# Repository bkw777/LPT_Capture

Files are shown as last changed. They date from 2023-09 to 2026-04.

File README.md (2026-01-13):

**NOTE: Only the top/default DB25_MicroUSB_BASIC version is tested and known good.**  
**All other versions are untested guesswork.**

# LPT Capture
Capture the output from a parallel printer port.

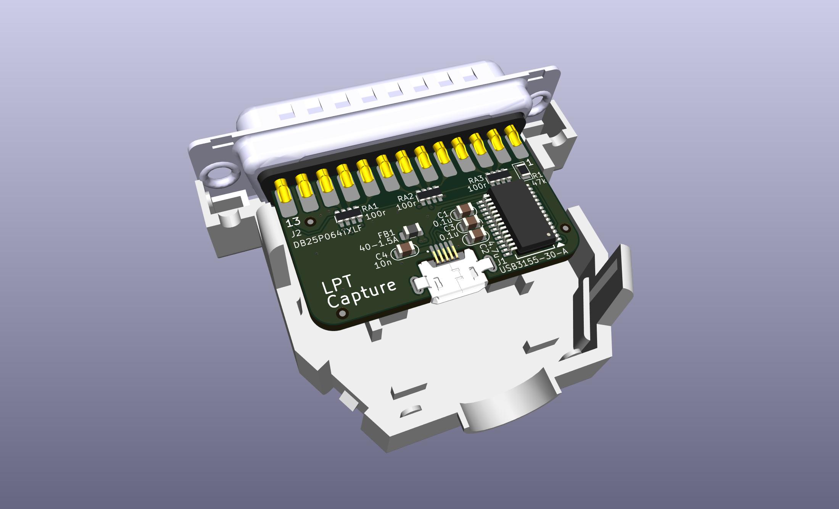
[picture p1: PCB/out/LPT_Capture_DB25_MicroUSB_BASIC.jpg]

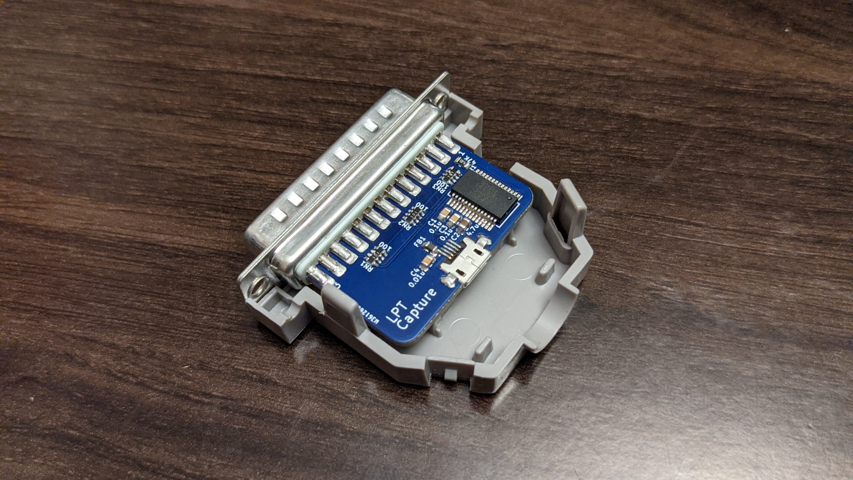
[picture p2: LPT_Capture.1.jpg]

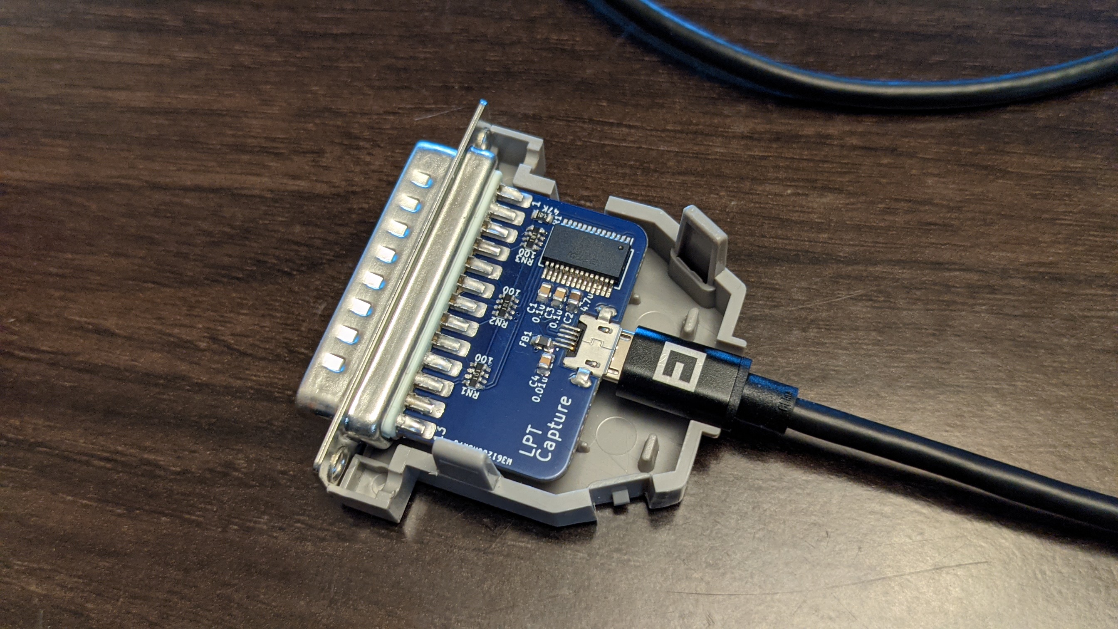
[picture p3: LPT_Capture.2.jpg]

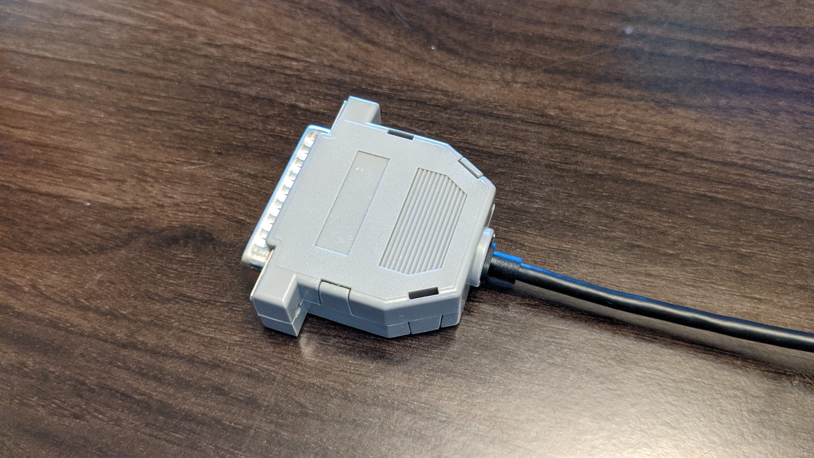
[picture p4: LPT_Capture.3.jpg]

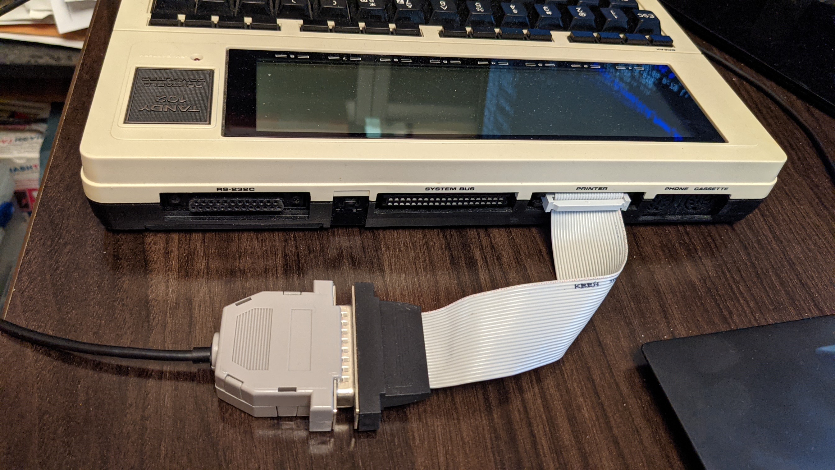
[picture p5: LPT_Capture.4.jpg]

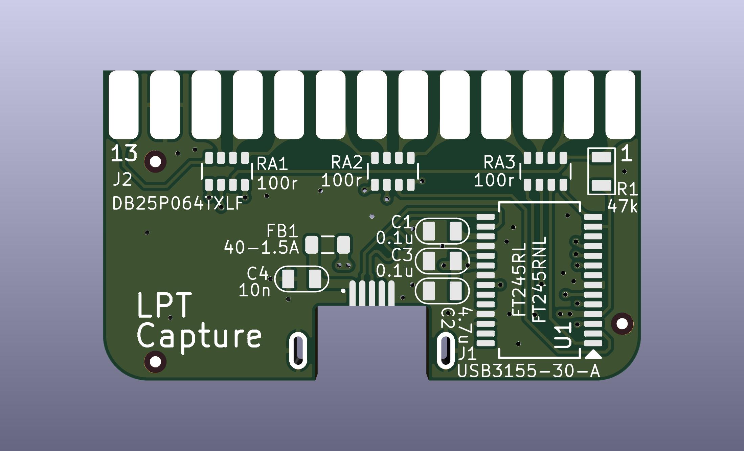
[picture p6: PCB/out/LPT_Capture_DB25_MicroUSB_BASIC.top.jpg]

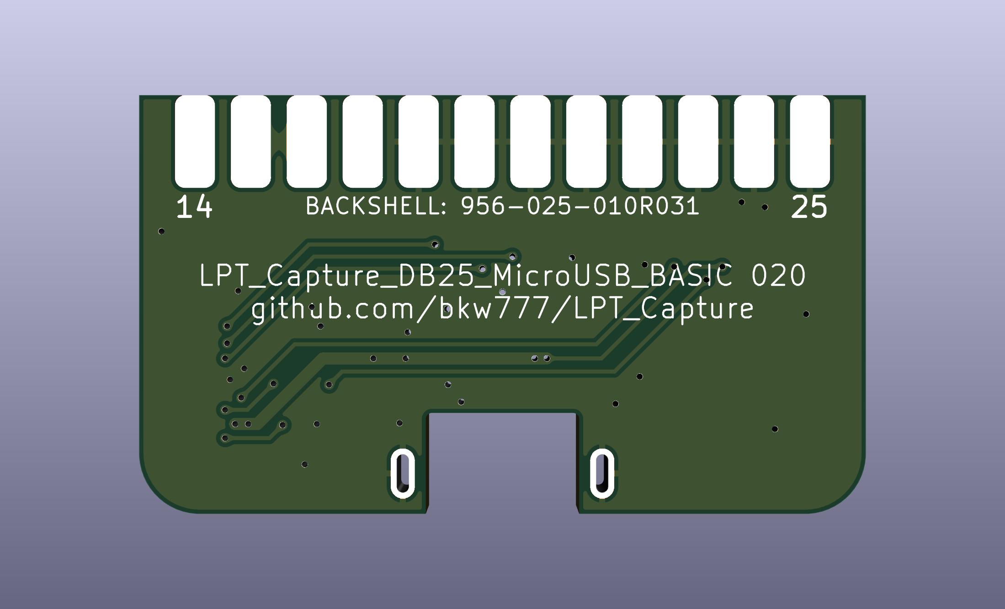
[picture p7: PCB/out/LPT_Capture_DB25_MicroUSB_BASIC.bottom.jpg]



PCB: [PCBWAY](https://www.pcbway.com/project/shareproject/LPT_Capture.html)  
BOM: [DigiKey](https://www.digikey.com/short/j7w00c9c)

# Usage
Plug the device directly into the parallel printer port on a vintage computer.  
Connect a modern machine to the mico-usb port.

The device appears as a usb-serial adapter to the modern machine. Drivers are standard in any modern os or platform.  
Use any serial comm program like PuTTY or TeraTerm or minicom or gnu screen etc to read the COM port.  
It doesn't matter what baud rate you select in the comm program.

Print to the LPT port on the vintage machine.

Read the data from the COM port on the modern machine.

This device essentially takes the place of a printer, and only only impliments the basic original Centronics interface, no ieee1284 epp ecp bi-directional etc.

# Other Versions
The default "DB25 MicroUSB BASIC" version above is tested.  
None of the rest of these are tested yet.

[DB25 MicroUSB FANCY](README_DB25_MicroUSB_FANCY.md)  
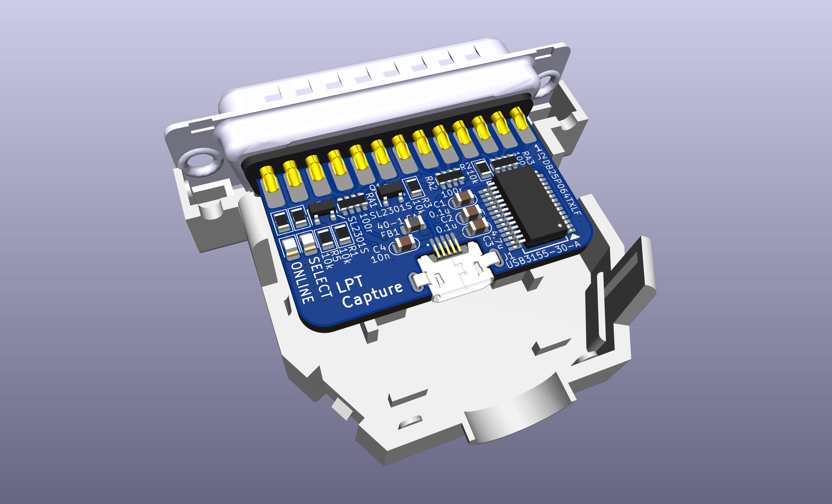
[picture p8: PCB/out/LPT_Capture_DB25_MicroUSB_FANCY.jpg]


[DB25 USBC BASIC](README_DB25_USBC_BASIC.md)  
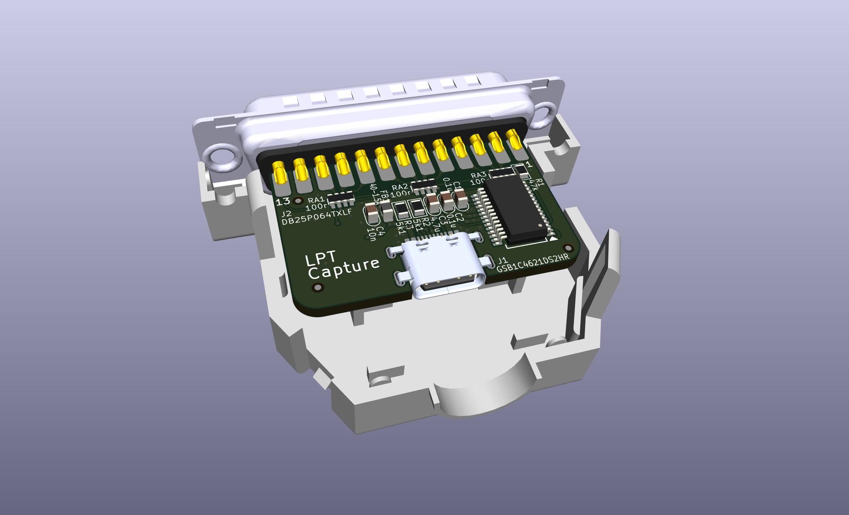
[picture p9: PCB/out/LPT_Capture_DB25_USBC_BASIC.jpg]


[DB25 USBC FANCY](README_DB25_USBC_FANCY.md)  
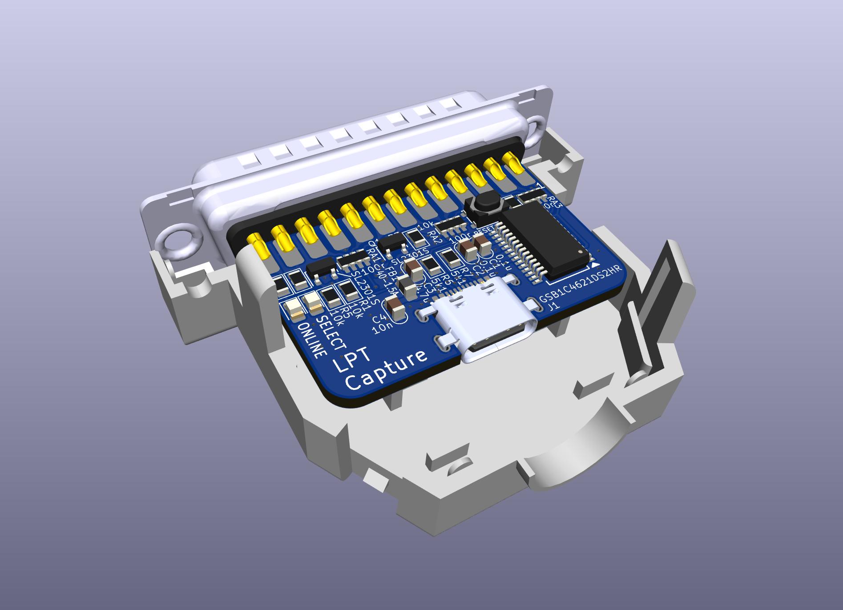
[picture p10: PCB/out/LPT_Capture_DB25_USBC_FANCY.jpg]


[CN36 USBC FANCY](README_CN36_USBC_FANCY.md)
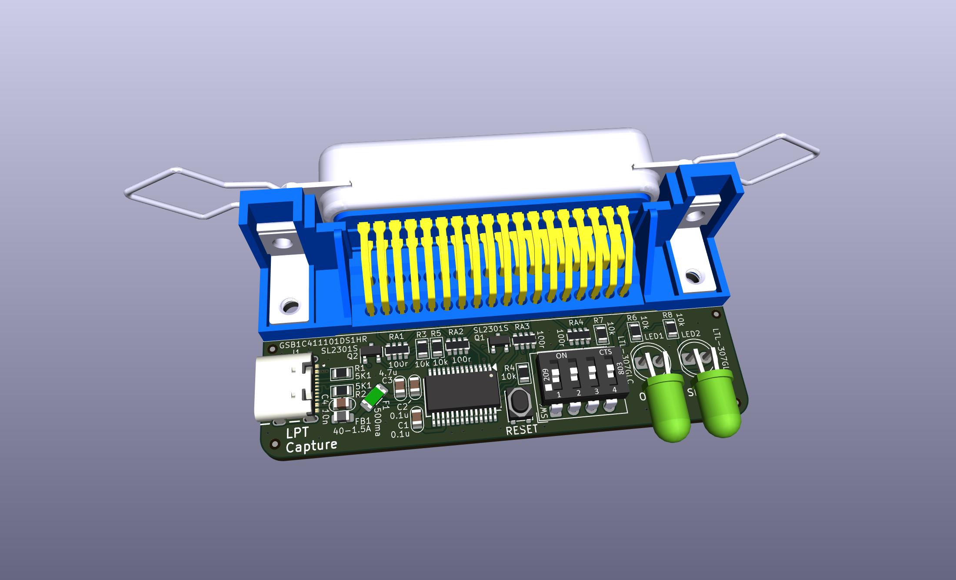
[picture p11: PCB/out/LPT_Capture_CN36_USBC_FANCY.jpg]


# Credits
[LptCap](https://www-user.tu-chemnitz.de/~heha/basteln/PC/LptCap/index.en.htm)

Differences:  
* KiCad instead of Eagle
* SSOP chip instead of QFN - easier to hand solder
* 0805 passives instead of 0603 - easier to hand solder
* microusb or usbc instead of miniusb
* mid-mount usb port - positions the plug in the center of the cable opening
* Snap-together backshell instead of screws & nuts
* VCCIO powered by VCC (5V) instead of 3V3OUT - LPT signals are 5V
* VBUS & VCC power conditioning per FT245R datasheet
* "fancy" versions impliment more signals (ONLINE, /SELIN, /RESET, /ERROR)
* CN36 version adds Peripheral Logic High and 5V power

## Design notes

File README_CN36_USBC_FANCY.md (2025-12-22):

# LPT Capture
Capture the output from a parallel printer port.

WIP NOT TESTED

* Centronics 36F  
* USB-C  
* ONLINE, /SELIN, /RESET signals  
* LEDS for ONLINE & /SELIN

This version is useful for hosts that don't have a standard IBM style db25 parallel printer port, but do have a printer cable that ends in a standard 36 pin Centronics plug.  
Examples: TRS-80 Model I, Model 100


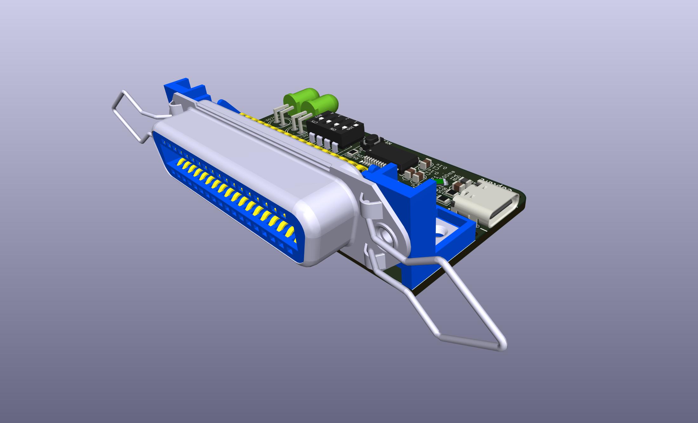
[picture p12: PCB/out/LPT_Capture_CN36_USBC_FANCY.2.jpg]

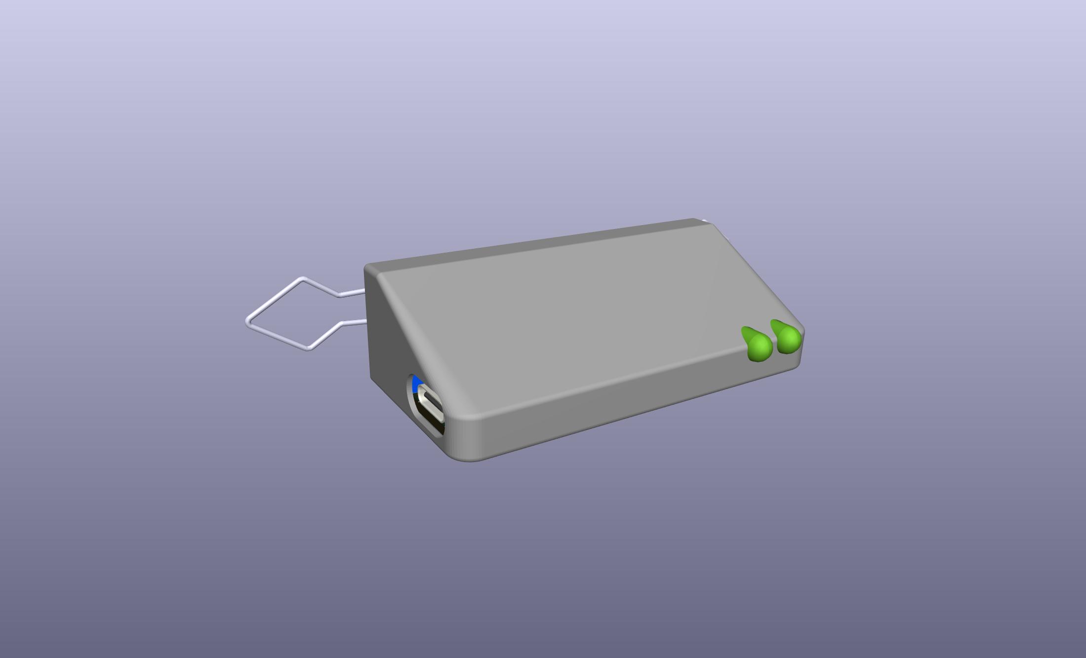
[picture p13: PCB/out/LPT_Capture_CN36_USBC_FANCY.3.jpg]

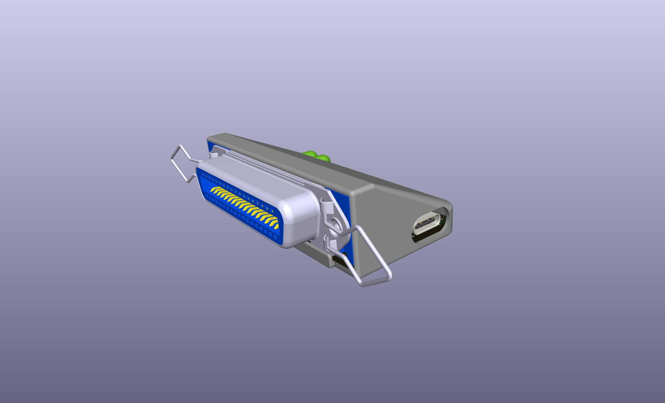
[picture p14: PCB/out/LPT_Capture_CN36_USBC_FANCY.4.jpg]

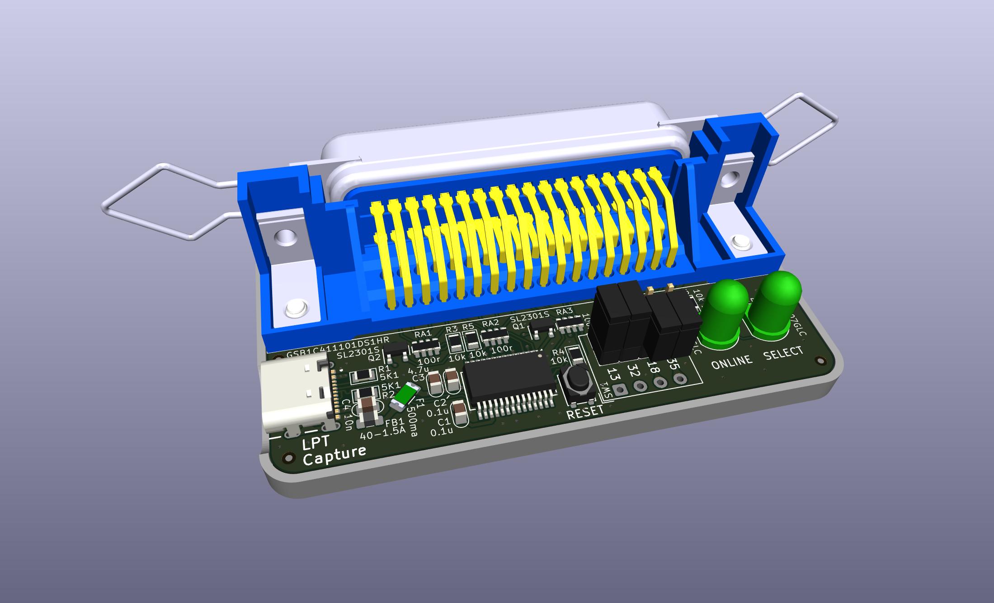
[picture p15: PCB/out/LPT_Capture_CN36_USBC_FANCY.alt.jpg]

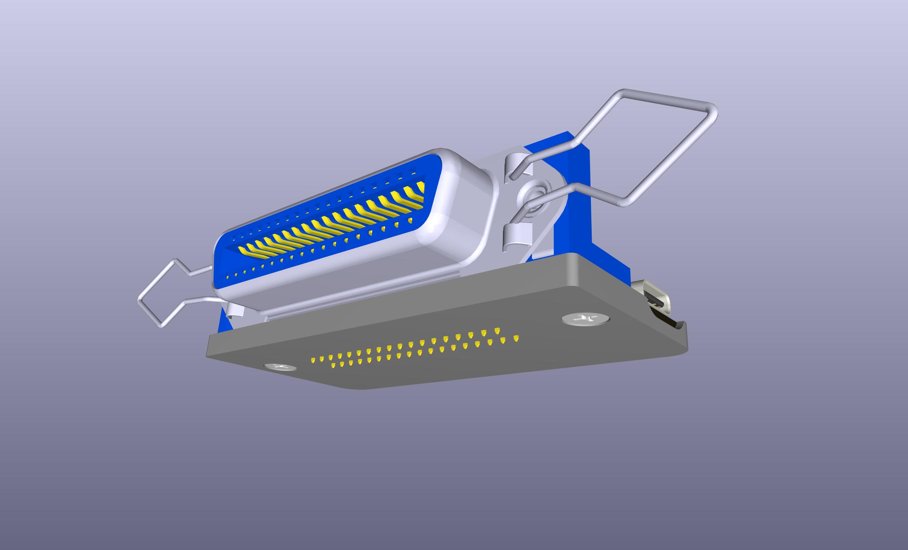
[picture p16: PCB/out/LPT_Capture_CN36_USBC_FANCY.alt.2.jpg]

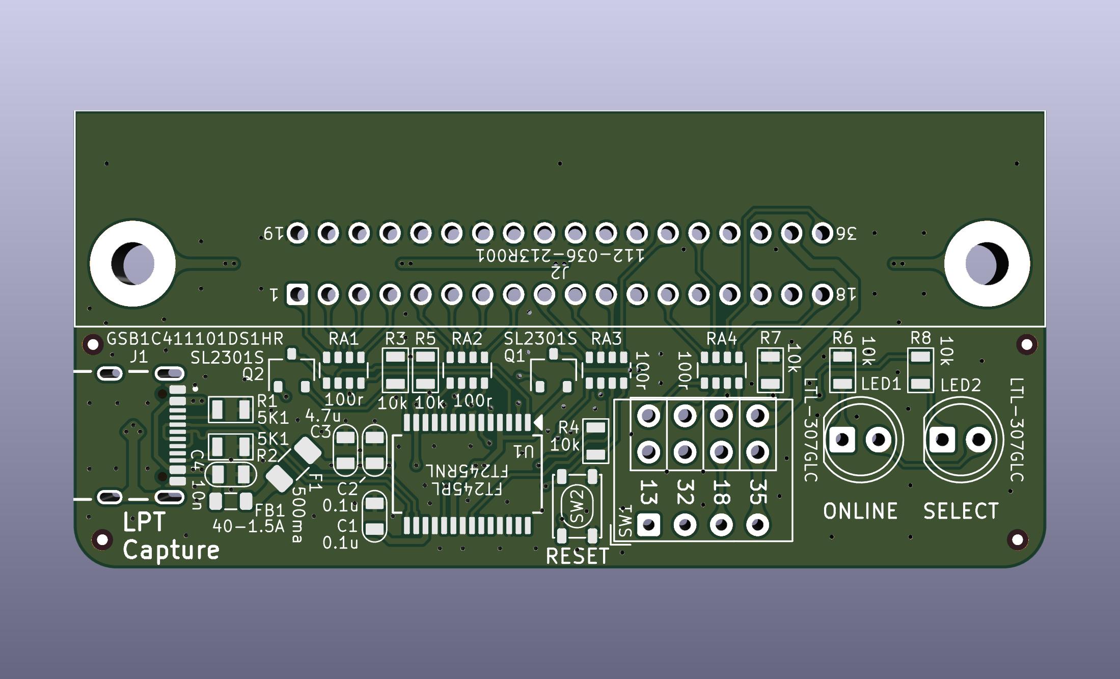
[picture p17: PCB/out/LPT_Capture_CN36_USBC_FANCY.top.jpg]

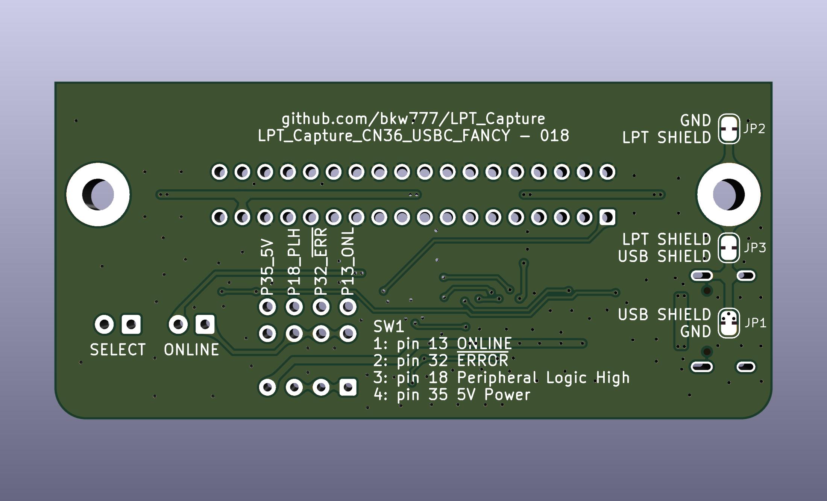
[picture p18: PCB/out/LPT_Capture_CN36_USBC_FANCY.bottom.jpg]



<!-- PCB: [PCBWAY](https://www.pcbway.com/project/shareproject/LPT_Capture.html)  --> 
BOM: [bom.csv](PCB/out/LPT_Capture_CN36_USBC_FANCY.bom.csv) <!-- [DigiKey](https://www.digikey.com/short/j7w00c9c) -->

# Credits
[LptCap](https://www-user.tu-chemnitz.de/~heha/basteln/PC/LptCap/index.en.htm)

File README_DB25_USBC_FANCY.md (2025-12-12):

# LPT Capture

WIP NOT TESTED

* DB25
* USB-C  
* ONLINE, /RESET, /SELIN  
* LEDS on ONLINE, /SELIN


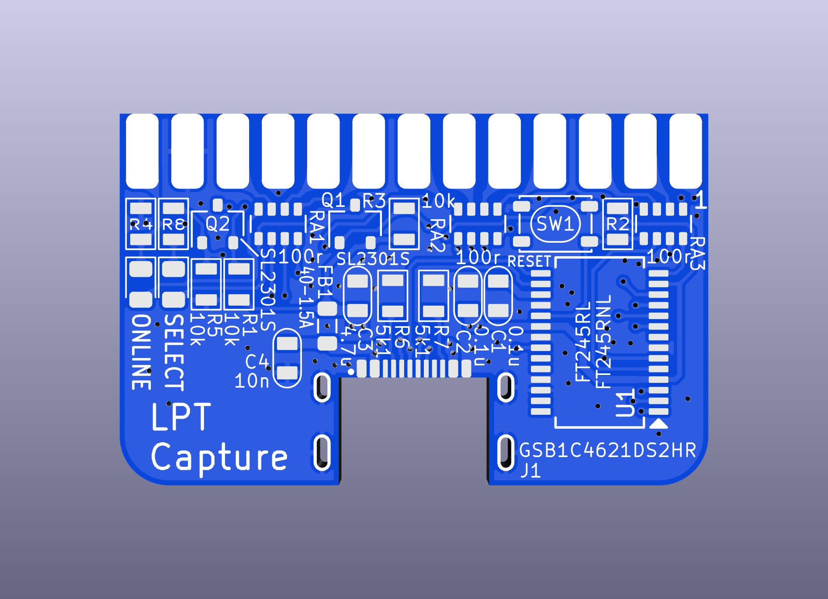
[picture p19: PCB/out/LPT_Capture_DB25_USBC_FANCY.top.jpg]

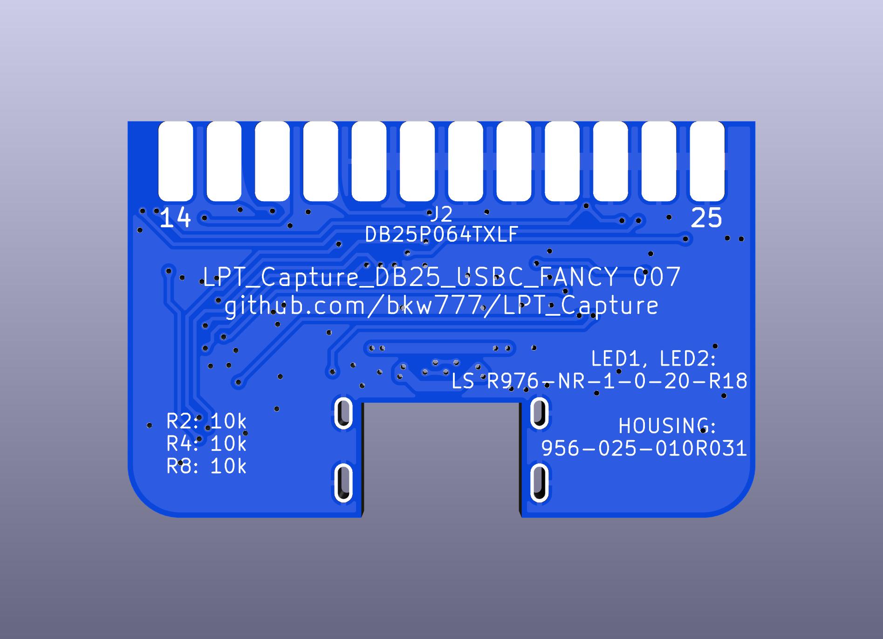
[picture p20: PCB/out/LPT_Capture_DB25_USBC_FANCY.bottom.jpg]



<!-- PCB: [OSHPark](https://oshpark.com/shared_projects/DqbtiuyI), [PCBWAY](https://www.pcbway.com/project/shareproject/LPT_Capture.html)  -->
BOM: [bom.csv](PCB/out/LPT_Capture_DB25_USBC_FANCY.bom.csv)  <!-- [DigiKey](https://www.digikey.com/short/hpfd7prz) -->

# Credits
[LptCap](https://www-user.tu-chemnitz.de/~heha/basteln/PC/LptCap/index.en.htm)

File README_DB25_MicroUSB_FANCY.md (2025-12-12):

# LPT Capture

WIP NOT TESTED

* DB25  
* MicroUSB  
* ONLINE, /RESET, /SELIN  
* LEDS on ONLINE, /SELIN


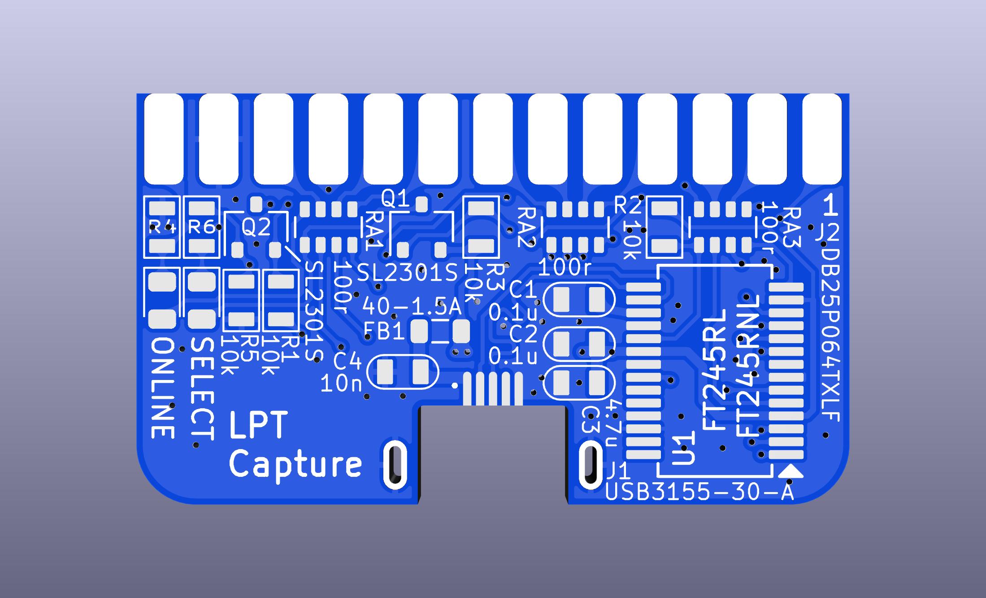
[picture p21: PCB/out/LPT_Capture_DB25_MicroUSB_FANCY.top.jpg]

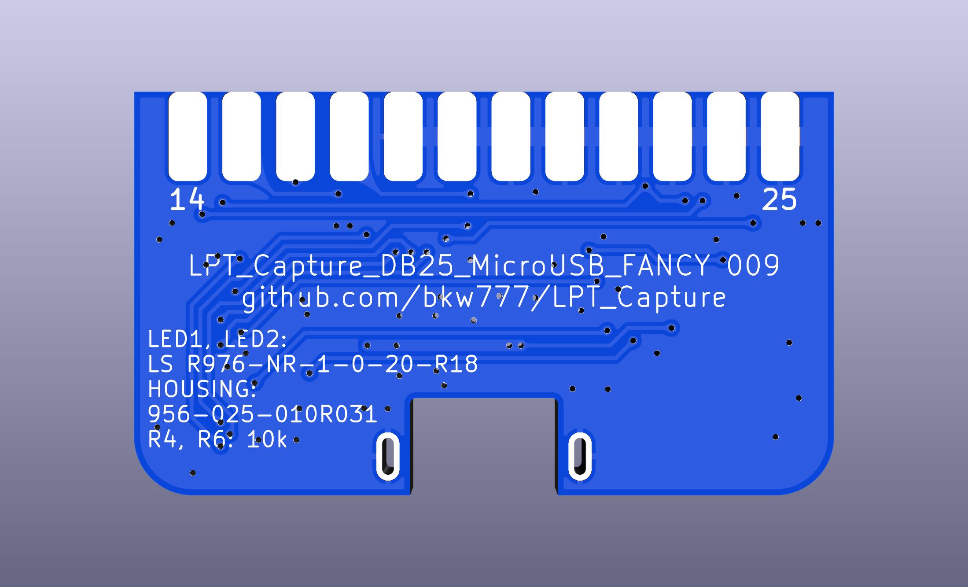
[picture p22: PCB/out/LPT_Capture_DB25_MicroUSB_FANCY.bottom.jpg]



<!-- PCB: [OSHPark](https://oshpark.com/shared_projects/DqbtiuyI), [PCBWAY](https://www.pcbway.com/project/shareproject/LPT_Capture.html)  -->
BOM: [bom.csv](PCB/out/LPT_Capture_DB25_MicroUSB_FANCY.bom.csv) <!--  [DigiKey](https://www.digikey.com/short/hpfd7prz) -->

# Credits
[LptCap](https://www-user.tu-chemnitz.de/~heha/basteln/PC/LptCap/index.en.htm)

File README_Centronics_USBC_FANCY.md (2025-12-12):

# LPT Capture
Capture the output from a parallel printer port.

WIP NOT TESTED

* Centronics 36F  
* USB-C  
* ONLINE, /SELIN, /RESET signals  
* LEDS for ONLINE & /SELIN

This version is useful for hosts that don't have a standard IBM style db25 parallel printer port, but do have a printer cable that ends in a standard 36 pin Centronics plug.  
Examples: TRS-80 Model I, Model 100

todo: printable encosure

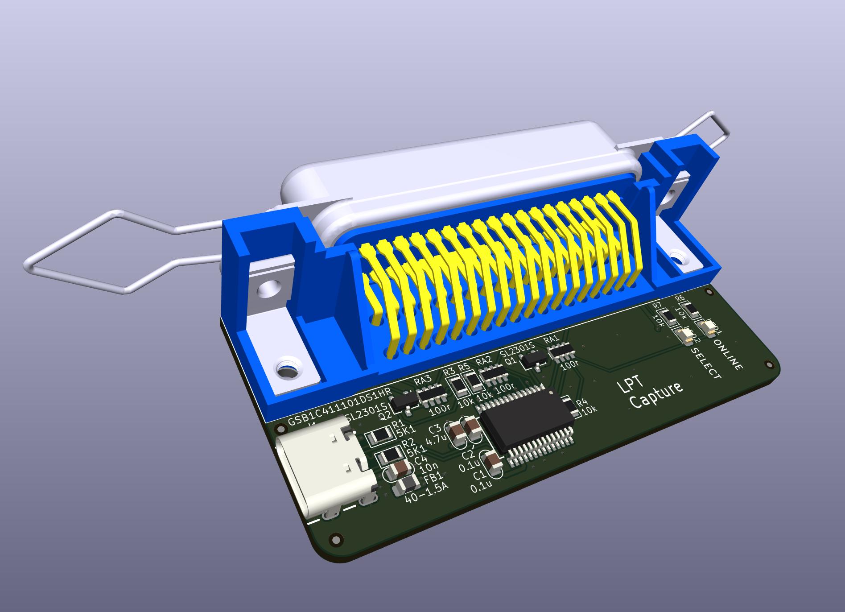
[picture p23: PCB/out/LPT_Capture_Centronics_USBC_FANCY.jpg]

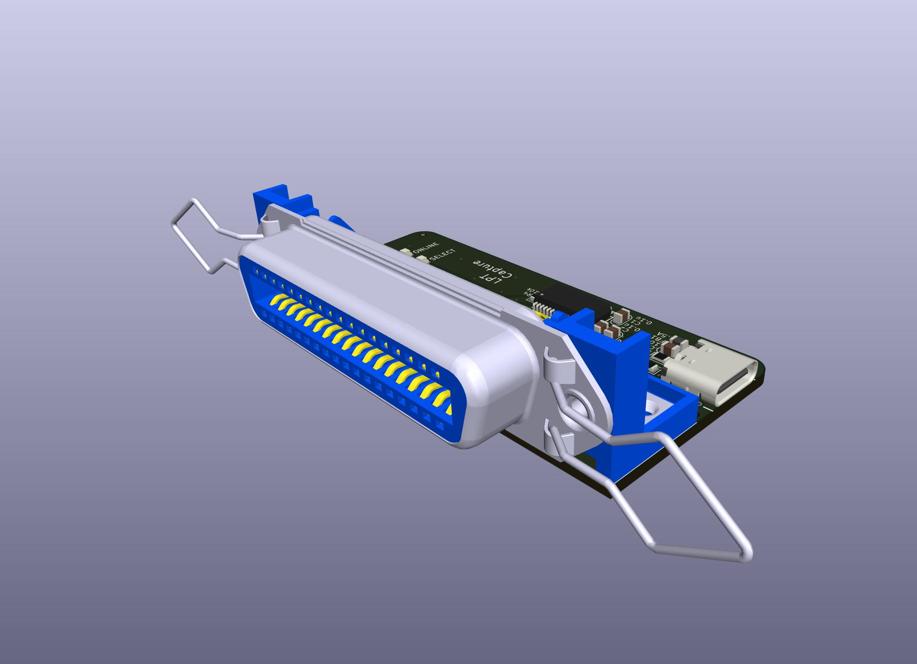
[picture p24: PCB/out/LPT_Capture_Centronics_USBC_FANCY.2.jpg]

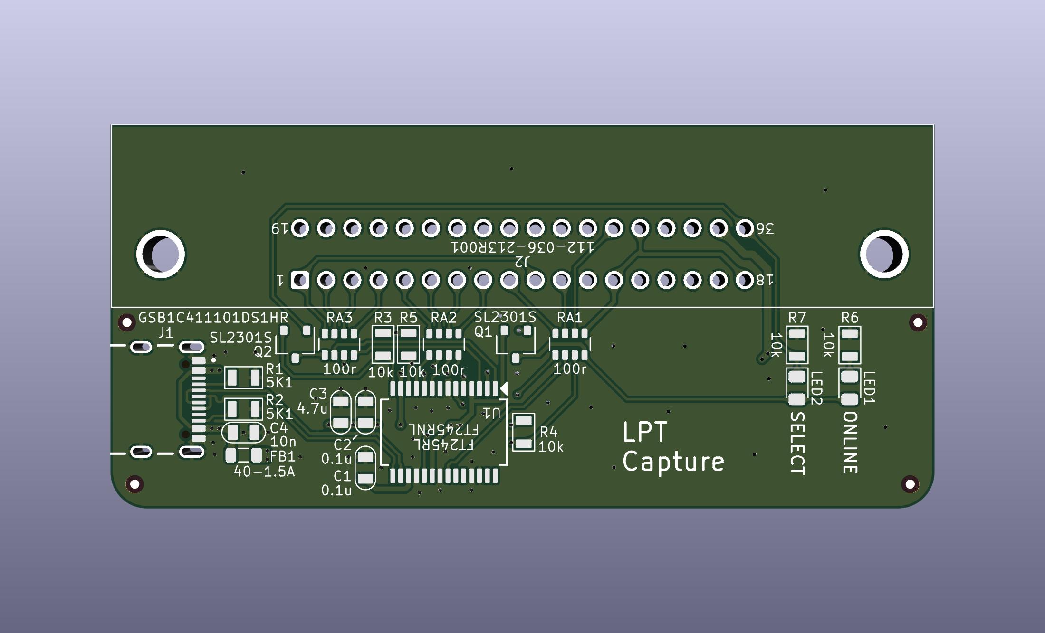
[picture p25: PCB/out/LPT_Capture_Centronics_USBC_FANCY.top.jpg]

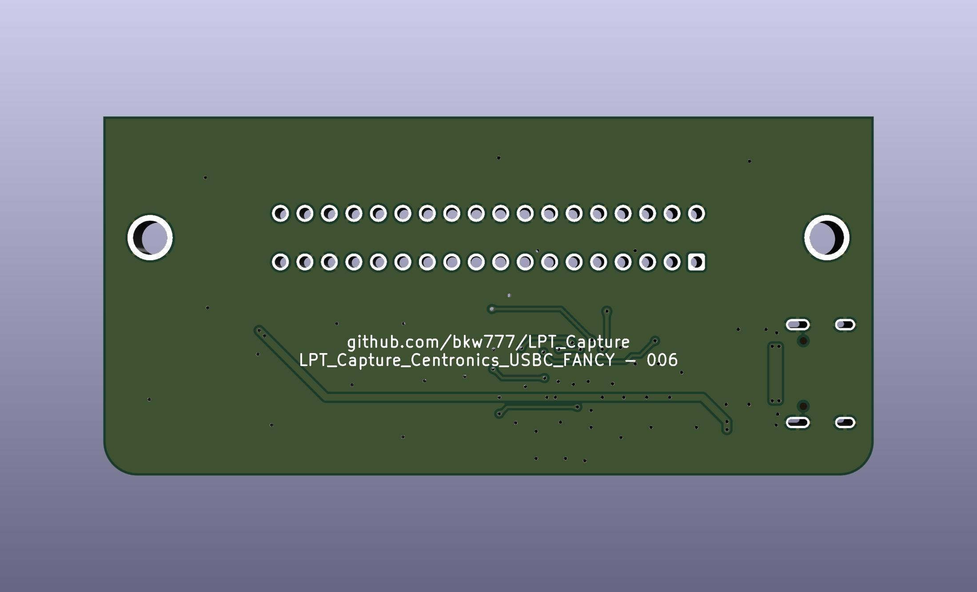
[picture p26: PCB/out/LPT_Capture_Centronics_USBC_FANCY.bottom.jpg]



<!-- PCB: [PCBWAY](https://www.pcbway.com/project/shareproject/LPT_Capture.html)  --> 
BOM: [bom.csv](PCB/out/LPT_Capture_Centronics_USBC_FANCY.bom.csv) <!-- [DigiKey](https://www.digikey.com/short/j7w00c9c) -->

# Credits
[LptCap](https://www-user.tu-chemnitz.de/~heha/basteln/PC/LptCap/index.en.htm)

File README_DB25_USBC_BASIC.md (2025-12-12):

# LPT Capture
Capture the output from a parallel printer port.

WIP NOT TESTED

* DB25
* USBC


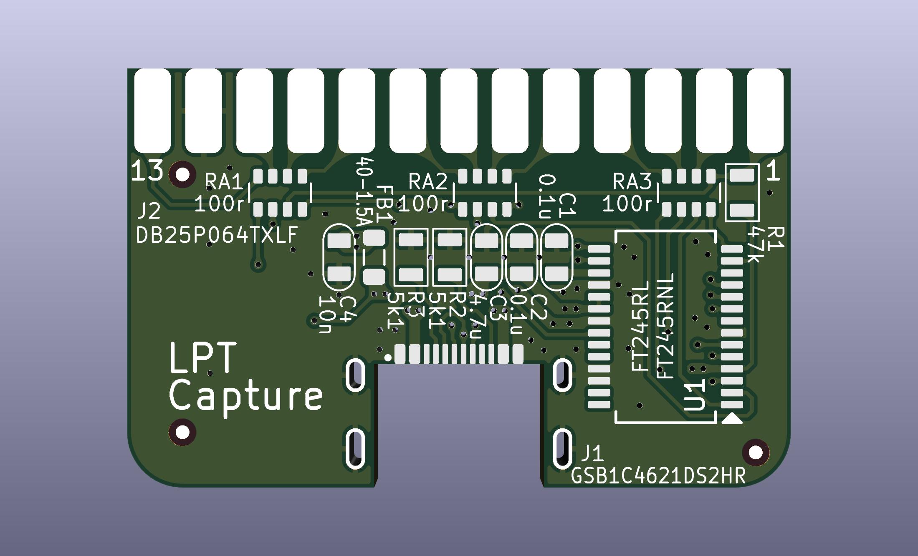
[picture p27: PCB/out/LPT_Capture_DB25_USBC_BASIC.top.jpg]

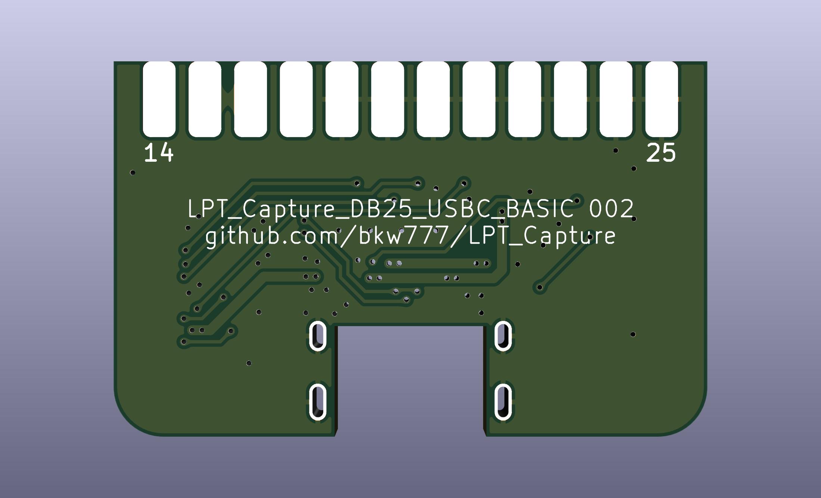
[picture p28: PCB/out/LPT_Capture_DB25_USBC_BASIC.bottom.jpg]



<!-- PCB: [PCBWAY](https://www.pcbway.com/project/shareproject/LPT_Capture.html)  -->
BOM: [bom.csv](PCB/out/LPT_Capture_DB25_USBC_BASIC.bom.csv) <!-- [DigiKey](https://www.digikey.com/short/j7w00c9c) -->

# Credits
[LptCap](https://www-user.tu-chemnitz.de/~heha/basteln/PC/LptCap/index.en.htm)

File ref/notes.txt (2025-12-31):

https://www.retroprinter.com/the-retro-printer-frequently-asked-questions/#collapse_468_1

"...
During development, we found various machines and computers which needed 5V on pin 13 (ERROR) and pin 32 (SELECT) in order to recognise that a working printer was connected.  Some equipment even appears to require 5V on pin 18.

However, since we started selling the v3 production model, we have found some equipment (or more likely the centronics cables) connects one or both of these lines to GND.  This drains the power from the Raspberry Pi and is fixed by using the supplied cable convertor for the v3 Retro-Printer module.  

The v4 Retro-Printer module includes changes to allow for more combinations of hardware and overcome the GND issue.  It has jumpers to enable or disable the 5V on pins 13, 18 and pin 32.
..."

https://ia800203.us.archive.org/5/items/f15_Parallel_Port_Complete/
https://ia800203.us.archive.org/5/items/f15_Parallel_Port_Complete/Parallel_Port_Complete_raw.zip
https://ia800203.us.archive.org/5/items/f15_Parallel_Port_Complete/Parallel_Port_Complete_Included_Disk.zip
https://ia800203.us.archive.org/5/items/f15_Parallel_Port_Complete/Parallel_Port_Complete_images_processed.pdf

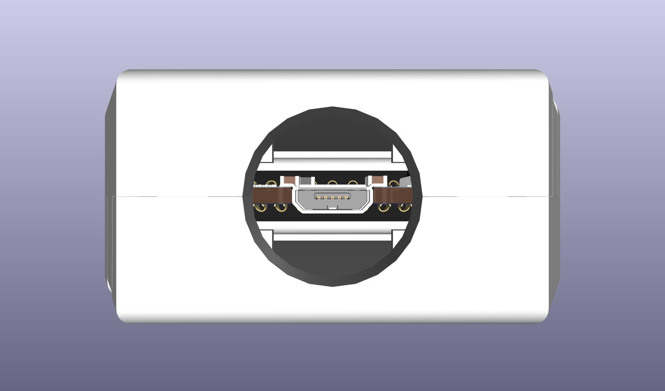
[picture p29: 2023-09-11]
PCB/out/LPT_Capture_usb_alignment.jpg

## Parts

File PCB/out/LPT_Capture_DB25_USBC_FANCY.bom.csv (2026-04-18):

Reference | Value | Qty | DNP | MPN | Description
C1,C2 | 0.1u | 2 |  | 885012207045 | CAP CER 0.1UF 16V X7R 0805
C3 | 4.7u | 1 |  | GRM21BR71C475KE51L | CAP CER 4.7UF 16V X7R 0805
C4 | 10n | 1 |  | 885012207039 | CAP CER 10000PF 16V X7R 0805
FB1 | 40-1.5A | 1 |  | MH2029-400Y | FERRITE BEAD 40 OHM 0805 1LN
J1 | GSB1C4621DS2HR | 1 |  | GSB1C4621DS2HR | USB 2.0-only 16P Type-C Receptacle connector
J2 | DB25P064TXLF | 1 |  | DB25P064TXLF | CONN D-SUB PLUG 25POS SOLDER CUP
LED1 | ONLINE | 1 |  | LS R976-NR-1-0-20-R18 | Light emitting diode
LED2 | SELECT | 1 |  | LS R976-NR-1-0-20-R18 | Light emitting diode
N1 | 956-025-010R031 | 1 |  | 956-025-010R031 | DB25 Backshell snap-together
Q1,Q2 | SL2301S | 2 |  | SL2301S | P-Channel MOSFET, SOT-23
R1,R2,R3,R4,R5,R8 | 10k | 6 |  | RC0805JR-0710KL | RES 10K OHM 5% 1/8W 0805
R6,R7 | 5k1 | 2 |  | RC0805FR-075K1L | RES 5K1 OHM 1% 1/8W 0805
RA1,RA2,RA3 | 100r | 3 |  | CAY16-101J4LF | RES ARRAY 4 RES 100 OHM 1206
SW1 | RESET | 1 |  | RKB2SJM250SMTR LFS | Push button switch, generic, two pins
U1 | FT245RL | 1 |  | FT245RNL | IC USB TO PARALLEL FIFO

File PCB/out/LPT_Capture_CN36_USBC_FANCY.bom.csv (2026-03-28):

Reference | Value | Footprint | Qty | DNP | MPN | Description
C1,C2 | 0.1u | 000_LOCAL:C_0805 | 2 |  | 885012207045 | CAP CER 0.1UF 16V X7R 0805
C3 | 4.7u | 000_LOCAL:C_0805 | 1 |  | GRM21BR71C475KE51L | CAP CER 4.7UF 16V X7R 0805
C4 | 10n | 000_LOCAL:C_0805 | 1 |  | 885012207039 | CAP CER 10000PF 16V X7R 0805
F1 | 500ma | 000_LOCAL:F_1206 | 1 |  | 0ZCJ0050AF2E | Resettable fuse, polymeric positive temperature coefficient, small symbol
FB1 | 40-1.5A | 000_LOCAL:L_0805 | 1 |  | MH2029-400Y | FERRITE BEAD 40 OHM 0805 1LN
J1 | GSB1C411101DS1HR | 000_LOCAL:USBC_Receptacle_16pin_top_mount | 1 |  | GSB1C411101DS1HR | USB 2.0-only 16P Type-C Receptacle connector
J2 | 112-036-213R001 | 000_LOCAL:Centronics_36F_RA_THT | 1 |  | 112-036-213R001 | Centronics 36pin female 0.85 pitch
JP1 | GND_USBSHLD | 000_LOCAL:SolderJumper-2_P1.3mm_Bridged_RoundedPad1.0x1.5mm | 1 |  |  | Jumper, 2-pole, small symbol, bridged
JP2 | GND_LPTSHLD | 000_LOCAL:SolderJumper-2_P1.3mm_Bridged_RoundedPad1.0x1.5mm | 1 |  |  | Jumper, 2-pole, small symbol, bridged
JP3 | USBSHLD_LPTSHLD | 000_LOCAL:SolderJumper-2_P1.3mm_Bridged_RoundedPad1.0x1.5mm | 1 |  |  | Jumper, 2-pole, small symbol, bridged
LED1,LED2 | LTL-307GLC | 000_LOCAL:LED_D5.0mm | 2 |  | LTL-307GLC | Light emitting diode
N1 | Housing | 000_LOCAL:Housing_CN36 | 1 |  |  | Housing
Q1,Q2 | SL2301S | 000_LOCAL:SOT-23 | 2 |  | SL2301S | P-Channel MOSFET, SOT-23
R1,R2 | 5K1 | 000_LOCAL:R_0805 | 2 |  | RC0805FR-075K1L | RES 5K1 OHM 1% 1/8W 0805
R3,R4,R5,R6,R7,R8 | 10k | 000_LOCAL:R_0805 | 6 |  | RC0805JR-0710KL | RES 10K OHM 5% 1/8W 0805
RA1,RA2,RA3,RA4 | 100r | 000_LOCAL:R_Array_Convex_4x0603 | 4 |  | CAY16-101J4LF | RES ARRAY 4 RES 100 OHM 1206 convex
SW1 | SW_DIP_x04 | 000_LOCAL:SW_DIP_SPST_Jumper_Dual_x04 | 1 |  | 209-4MS | 4x DIP Switch, Single Pole Single Throw (SPST) switch, small symbol
SW2 | RESET | 000_LOCAL:SW_SPST_PTS810 | 1 |  | RKB2SJM250SMTR LFS | Push button switch, generic, two pins
U1 | FT245RL | 000_LOCAL:SSOP-28 | 1 |  | FT245RNL | IC USB TO PARALLEL FIFO 28-SSOP

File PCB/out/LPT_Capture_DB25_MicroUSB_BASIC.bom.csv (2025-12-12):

Reference | Value | Datasheet | Footprint | Qty | DNP | MPN | Description
C1,C3 | 0.1u | datasheets/885012207045.pdf | 000_LOCAL:C_0805 | 2 |  | 885012207045 | CAP CER 0.1UF 16V X7R 0805
C2 | 4.7u | datasheets/GRM21BR71C475KE51-01.pdf | 000_LOCAL:C_0805 | 1 |  | GRM21BR71C475KE51L | CAP CER 4.7UF 16V X7R 0805
C4 | 10n | datasheets/885012207039.pdf | 000_LOCAL:C_0805 | 1 |  | 885012207039 | CAP CER 10000PF 16V X7R 0805
FB1 | 40-1.5A | datasheets/mh.pdf | 000_LOCAL:L_0805 | 1 |  | MH2029-400Y | FERRITE BEAD 40 OHM 0805 1LN
J1 | USB3155-30-A | datasheets/usb3155.pdf | USB3155-xx-x | 1 |  | USB3155-30-A | MICRO B SKT, HORIZONTAL MID SMT
J2 | DB25P064TXLF | datasheets/io_dsub_brochure.pdf | 000_LOCAL:DSUB-25_Male_EdgeMount_P2.77mm | 1 |  | DB25P064TXLF | CONN D-SUB PLUG 25POS SLDR CUP
N1 | 956-025-010R031 | datasheets/mhccovxx-sn-xx.pdf | 000_LOCAL:DSUB-25_Housing | 1 |  | 956-025-010R031 | 25 WAY D-SUB HOOD PLASTIC TOP EN
R1 | 47k | ~ | 000_LOCAL:R_0805 | 1 |  | RC0805JR-0747KL | RES 47K OHM 5% 1/8W 0805
RA1,RA2,RA3 | 100r | datasheets/CATCAY.pdf | 000_LOCAL:R_Array_Convex_4x0603 | 3 |  | CAY16-101J4LF | RES ARRAY 4 RES 100 OHM 1206 convex
U1 | FT245RL | datasheets/FT245RN.pdf | 000_LOCAL:SSOP-28 | 1 |  | FT245RNL | IC USB TO PARALLEL FIFO 28-SSOP

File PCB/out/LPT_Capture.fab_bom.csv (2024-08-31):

Reference | Value | Datasheet | Footprint | Qty | DNP | MPN | Description
C1,C3 | 100n | datasheets/885012207045.pdf | 000_LOCAL:C_0805 | 2 |  | 885012207045 | CAP CER 0.1UF 16V X7R 0805
C2 | 4.7u | datasheets/GRM21BR71C475KE51-01.pdf | 000_LOCAL:C_0805 | 1 |  | GRM21BR71C475KE51L | CAP CER 4.7UF 16V X7R 0805
C4 | 10n | datasheets/885012207039.pdf | 000_LOCAL:C_0805 | 1 |  | 885012207039 | CAP CER 10000PF 16V X7R 0805
FB1 | 40-1.5A | datasheets/mh.pdf | 000_LOCAL:L_0805 | 1 |  | MH2029-400Y | FERRITE BEAD 40 OHM 0805 1LN
J1 | USB3155-XX-X_REVA | datasheets/usb3155.pdf | 000_LOCAL:GCT_USB3155-XX-X_REVA | 1 |  | USB3155-30-A | MICRO B SKT, HORIZONTAL MID SMT
J2 | DB25 Male | datasheets/ASS_4884_CO.pdf | 000_LOCAL:DSUB-25_Male_EdgeMount_P2.77mm | 1 |  | A-DS 25 LL/Z | CONN D-SUB PLUG 25POS SLDR CUP
N1 | DB25_backshell | datasheets/mhccovxx-sn-xx.pdf | 000_LOCAL:db25_backshell | 1 |  | MHCCOV-25-SN-LG | 25 WAY D-SUB HOOD PLASTIC TOP EN
R1 | 47k | ~ | 000_LOCAL:R_0805 | 1 |  | RC0805JR-0747KL | RES 47K OHM 5% 1/8W 0805
RA1,RA2,RA3 | 100 | datasheets/CATCAY.pdf | 000_LOCAL:R_Array_Convex_4x0603 | 3 |  | CAY16-101J4LF | RES ARRAY 4 RES 100 OHM 1206 convex
U1 | FT245RL | datasheets/FT245R.pdf | 000_LOCAL:SSOP-28 | 1 |  | FT245RL | IC USB TO PARALLEL FIFO 28-SSOP

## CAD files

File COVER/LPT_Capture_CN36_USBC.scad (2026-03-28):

// Enclosure for LPT_Capture CN36_USBC_FANCY
//
// Use the customizer pane to select options.
// PANHEAD or FLATHEAD requires 2  #4-40 x 1/4" screws.

NOTES = ""; // just a way to provide per-config notes in the customizer

STYLE = "SHELL"; // [SHELL,TRAY,PLATE]
FASTENER = "CLIP"; // [CLIP,PAN HEAD,FLAT HEAD,FLAT+CLIP,PAN+CLIP]
DIP_SWITCH = "LOW PROFILE"; // [LOW PROFILE,JUMPERS,PIANO,STANDARD]
LEDS = "HORIZONTAL"; // [HORIZONTAL, VERTICAL, SMT]
CN36 = "112-036-213R002"; // [112-036-213R002,1734044-1,5552742-1]

////////////////////////////////////////
SHELL = (STYLE=="SHELL");
TRAY = (STYLE=="TRAY");
PLATE = (STYLE=="PLATE");
CLIP = (FASTENER=="CLIP" || FASTENER=="FLAT+CLIP" || FASTENER=="PAN+CLIP");
PAN_HEAD = (FASTENER=="PAN HEAD" || FASTENER=="PAN+CLIP");
FLAT_HEAD = (FASTENER=="FLAT HEAD" || FASTENER=="FLAT+CLIP");
SW_LOW = (DIP_SWITCH=="LOW PROFILE");
SW_STD = (DIP_SWITCH=="STANDARD");
SW_PIANO = (DIP_SWITCH=="PIANO");
SW_JMP = (DIP_SWITCH=="JUMPERS");
LED_HORIZ = (LEDS=="HORIZONTAL");
LED_VERT = (LEDS=="VERTICAL");
LED_SMT = (LEDS=="SMT");
CN36_A = (CN36=="112-036-213R002");
CN36_B = (CN36=="1734044-1");
CN36_C = (CN36=="5552742-1");

////////////////////////////////////////

/* [Hidden] */
pcb_thickness = 1.6;
pcb_w = 68;
pcb_d = 32;
pcb_r = 3; // corner radius

/* [Global] */

// 0 = auto, based on usb_clearance and led_diameter.
rear_height = 3; // 0.1

fitment_clearance = 0.1;

fc = fitment_clearance;
wall_thickness = 1; // 0.1
rear_wall_ext = -(pcb_d/2 + fc + wall_thickness);

lip = 1;

screw_hole_id = 3; // #4-40 screw, 2.845 od

usb_clearance = 2; // 0.1

/* [Hidden] */
cn36_top_depth =
  CN36_C ? 15 :
  7;
cn36_height = 
  CN36_B ? 15.2 :
  CN36_C ? 15.8 :
  15.6;
cn36_y = 5.3;
cn36_post_seperation = 59.74;
cn_h = cn36_height;
cn_vd = cn36_top_depth;

/* [Global] */
CUT_LED_HOLES = true;
led_diameter = 5; // 0.1

/* [Hidden] */
leds_y = -7;
led1_x = 28;
led2_x = 21;
leds_ox = abs(led1_x-led2_x)/2; // x offset (half of center to center)
leds_x = min(led1_x,led2_x) + leds_ox; // center x pos
led_l = 10;

/* [Global] */
CUT_DIPSW_HOLE = false;

// 0=auto
dipsw_hole_bottom = 0; // 0.1
// 0=auto
dipsw_horiz_hole_height = 0; // 0.1
// 0=auto
dipsw_vert_hole_height = 0; // 0.1
dipsw_hole_width = 12.8; // 0.1
// 0=auto
dipsw_horiz_hole_depth = 0; // 0.1
// 0=auto
dipsw_vert_hole_depth = 0; // 0.1
// 0=auto
dipsw_horiz_hole_outside_y = 0; // 0.1
// 0=auto
dipsw_vert_hole_outside_y = 0; // 0.1
dipsw_hole_corner_radius = 0.5; // 0.1

/* [Hidden] */

sw_x = 10.0125;
sw_y = -9.144;
sw_d = 
  SW_STD ? 17 :
  SW_PIANO ? 17 :
  SW_JMP ? 17 :
  15.24; // switch body depth

sw_r = dipsw_hole_corner_radius;

//sw_inset = rear_wall_ext - sw_y + sw_d/2;

sw_w = dipsw_hole_width;

// dipsw horizontal cut cube height
sw_hh =
  dipsw_horiz_hole_height ? dipsw_horiz_hole_height :
  SW_STD ? 0 :
  SW_PIANO ? 5 :
  SW_JMP ? 9 :
  0;
// dipsw vertical cut cube height
sw_hv = cn36_height+2;

// dipsw horizontal cut cube depth
sw_dh =
  dipsw_horiz_hole_depth ? dipsw_horiz_hole_depth :
  SW_PIANO ? 14 :
  0;
// dipsw vertical cut cube depth
sw_dv =
  dipsw_vert_hole_depth ? dipsw_vert_hole_depth :
  SW_STD ? 10.5 :
  SW_PIANO ? 7 :
  SW_JMP ? 10.5 :
  8;

// dipsw horizontal cut cube y pos
sw_yh =
  dipsw_horiz_hole_outside_y ? dipsw_horiz_hole_outside_y :
  rear_wall_ext - sw_r;
// dipsw verticalal cut cube y pos
sw_yv =
  dipsw_vert_hole_outside_y ? dipsw_vert_hole_outside_y :
  SW_PIANO ? rear_wall_ext - sw_r :
  sw_y-sw_dv/2;

sw_z =
  dipsw_hole_bottom ? dipsw_hole_bottom :
  SW_STD ? 1 :
  SW_PIANO ? 3 :
  SW_JMP ? 1 :
  1;
sw_zz = sw_z?sw_z:(fc+wall_thickness);

usb_h = 3.2; // thickness of usbc
usb_w = 9;
usb_cx = (usb_w - usb_h)/2;
usb_r = usb_h/2 + usb_clearance;
usb_H = usb_h + usb_clearance*2;
usb_W = usb_w + usb_clearance*2;
echo("usb hole height",usb_H);
echo("usb hole width",usb_W);
assert(usb_H>=6.5);
assert(usb_W>=12.5);

usb_y = -6.85;
usb_z = 1.7; // center of usbc above pcb top (not exactly usb_h/2)

post_id = screw_hole_id;
screw_head_od = post_id*2;
post_od = screw_head_od + wall_thickness*2;
screw_head_thickness = 2.1; // #4-40 pan head is just over 2mm thick

// rear_height=0 -> auto
rh = pcb_thickness + fc + (rear_height?rear_height:max(usb_z+usb_r,led_diameter+1));


// space between bottom of pcb and top of bottom wall
gap =
  (PAN_HEAD)?screw_head_thickness:
  (FLAT_HEAD)?screw_head_thickness-wall_thickness:
  1;
base_thickness = gap + wall_thickness;

// reset button boss
rb_x = 1.2;
rb_y = 11.65;
rb_z = 4.4;
rb_w = 3.2;
rb_d = 4.5;
rb_h = cn_h;

// arc smoothness
//$fn = 32;
$fa = 6;
$fs = 0.1;

////////////////////////////////////////////////////////////////////////////////////////

minimum_wall_thickness = 0.8;
assert (wall_thickness>minimum_wall_thickness-0.1);  // >= test doesn't work?


////////////////////////////////////////////////////////////////////////////////////////

use <lib/handy.scad>;

module bisect (x=0) {
  w = pcb_w/2+fc+wall_thickness+1;
  d = 1+wall_thickness+fc+pcb_d+fc+wall_thickness+1;
  h = 1+base_thickness+fc+pcb_thickness+cn_h+fc+wall_thickness+1;
  difference() {
    children();
    translate([x,-d/2,-fc-base_thickness-1]) cube([w,d,h]);
  }
}

module pcb () {
  import("lib/LPT_Capture_CN36_USBC_FANCY.notht.pcb.stl");
}

module cn36 () {
  translate([0,cn36_y,pcb_thickness]) if (CN36_B) import("lib/cn36_1734044-1.stl");
  else if (CN36_C) import("lib/cn36_5552742-1.stl");
  else import("lib/cn36_112-036-213R002.stl");
}

module dipsw () {
  translate([sw_x,sw_y,pcb_thickness]) if (SW_JMP) translate([0,2.54,0]) import("lib/dipsw_jumpers.stl");
  else if (SW_STD) import("lib/dipsw_standard.stl");
  else if (SW_LOW) import("lib/dipsw_lowprofile.stl");
  else if (SW_PIANO) import("lib/dipsw_piano.stl");
}

module leds () {
  translate([leds_x,leds_y,pcb_thickness]) mirror_copy([1,0,0]) translate([leds_ox,0,0])
    if (LED_HORIZ) import("lib/led_horizontal.stl");
    else if (LED_VERT) import("lib/led_vertical.stl");
    else if (LED_SMT) import("lib/led_smt.stl");
}

module screw () {
  if (FLAT_HEAD) %import("lib/flathead.stl");
  if (PAN_HEAD) %import("lib/panhead.stl");
}

module pcb_outline (x=pcb_w,y=pcb_d,z=base_thickness,R=pcb_r,r=0) {
  hull() {
    if (r) mirror_copy([1,0,0]) translate([x/2-r,y/2-r,0]) cylinder(h=z,r=r,center=true);
    else translate([0,y/2-1,0]) cube([x,2,z],center=true);
    mirror_copy([1,0,0]) translate([x/2-R,-y/2+R,0])
      cylinder(h=z,r=R,center=true);
  }
}

module screw_posts () {
  x = cn36_post_seperation/2;
  if (PAN_HEAD || FLAT_HEAD) mirror_copy([1,0,0]) translate([x,cn36_y,-gap-fc]) {
    cylinder(d=post_od,h=gap);
    translate([0,-post_od/2,0]) cube([post_od/2,post_od,gap]);
  }
}

module screw_holes () {
  x = cn36_post_seperation/2;
  if (PAN_HEAD || FLAT_HEAD) mirror_copy([1,0,0]) translate([x,cn36_y,-base_thickness-fc]) {
    // screw holes
    cylinder(h=base_thickness+fc*2,d=post_id);
    // screw head pockets
    if (FLAT_HEAD) {
      cylinder(h=base_thickness+fc,d2=post_id,d1=screw_head_od);
      translate([0,0,fc*2]) screw();
    }
    else {
      translate([0,0,-wall_thickness]) cylinder(h=base_thickness,d=screw_head_od);
      translate([0,0,gap]) screw();
    }

  }
}

/////////////////////////////////////////////////////////////////////////////////////////
// FULL MODELS
/////////////////////////////////////////////////////////////////////////////////////////

// Simplest and smallest
// todo: snap option
module plate () {
  difference() {
    translate([0,0,-base_thickness/2]) pcb_outline();

    union() {
      t = base_thickness;
      // pockets for solder legs
      translate([0,0,-t/2+wall_thickness]) {
        // cn36
        translate([0,cn36_y,0]) cube([40,7,t],center=true);
        // dipsw
        translate([sw_x,sw_y,0]) cube([10,10,t],center=true);
        // leds
        translate([leds_x,leds_y,0]) cube([leds_ox*4-1,3,t],center=true);
      }

      screw_holes();
    }

  }
}

// Slightly fancier than plate()
// protects the pcb edge
// easy to print
// does not require rounded_cube()
// todo: snap option
module tray () {
  th = wall_thickness + gap + pcb_thickness;

  difference() {
    union() {
      // main tray
      difference() {
        union() {
          // main
          translate([0,0,-th/2+pcb_thickness])
            pcb_outline(x=pcb_w+wall_thickness*2+fc*2,y=pcb_d+wall_thickness*2+fc*2,z=th,R=pcb_r+wall_thickness+fc,r=wall_thickness);
        }

        union() {
          // pcb tray
          translate([0,0,th/2-fc])
          pcb_outline(x=pcb_w+fc*2,y=pcb_d+fc*2,z=th,R=pcb_r+fc);
          // gap cavity
          translate([0,0,th/2-gap])
          pcb_outline(x=pcb_w-lip*2,y=pcb_d-lip*2,z=th,R=pcb_r-wall_thickness);
          // usb
          translate([-pcb_w/2,usb_y,pcb_thickness+usb_z]) rotate([90,0,-90])
          hull() mirror_copy([1,0,0])
          translate([usb_cx,0,0])
          cylinder(h=wall_thickness+fc*2,r=usb_r);

        }
      }
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

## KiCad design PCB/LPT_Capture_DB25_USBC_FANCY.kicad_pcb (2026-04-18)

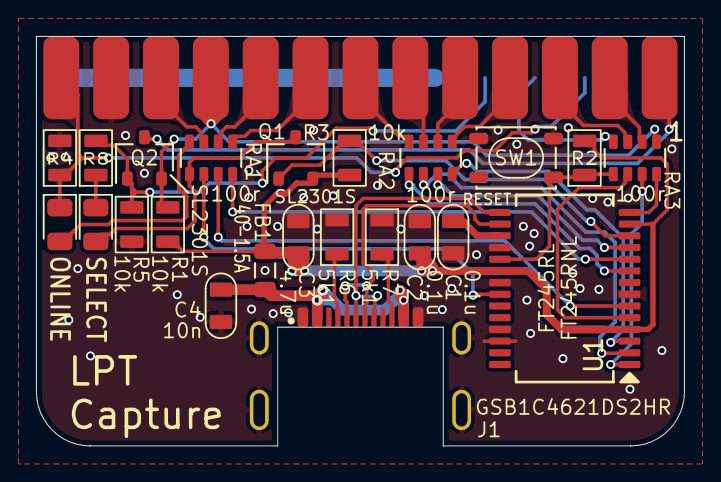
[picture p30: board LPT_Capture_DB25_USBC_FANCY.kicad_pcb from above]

Board: 2 copper layers, 36.0 x 22.8 mm, 25 parts (0 on the bottom side), 37 nets.

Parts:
C1, C2: 0.1u; C_0805
C3: 4.7u; C_0805
C4: 10n; C_0805
FB1: 40-1.5A; L_0805
J1: GSB1C4621DS2HR; USBC_Receptacle_16pin_mid_mount
J2: DB25P064TXLF; DSUB-25_Male_EdgeMount_P2.77mm
LED1: ONLINE; LED_0805
LED2: SELECT; LED_0805
N1: 956-025-010R031; DSUB-25_Housing
Q1, Q2: SL2301S; SOT-23
R1, R2, R3, R4, R5, R8: 10k; R_0805
R6, R7: 5k1; R_0805
RA1, RA2, RA3: 100r; R_Array_Convex_4x0603
SW1: RESET; SW_SPST_PTS810
U1: FT245RL; SSOP-28

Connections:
/3v3: C1.2, U1.17 (3V3OUT)
/BUSY: J2.11, RA1.7 (R2.2)
/D0: RA3.3 (R3.1), U1.1 (D0)
/D1: RA3.2 (R2.1), U1.5 (D1)
/D2: RA2.4 (R4.1), U1.3 (D2)
/D3: RA2.3 (R3.1), U1.11 (D3)
/D4: RA2.2 (R2.1), U1.2 (D4)
/D5: RA2.1 (R1.1), U1.9 (D5)
/D6: RA1.4 (R4.1), U1.10 (D6)
/D7: RA1.3 (R3.1), U1.6 (D7)
/ON: LED2.2 (A), Q1.3 (D), RA1.1 (R1.1)
/ONLINE: J2.13, J2.15, LED1.1 (K), R4.1
/PD0: J2.2, RA3.6 (R3.2)
/PD1: J2.3, RA3.7 (R2.2)
/PD2: J2.4, RA2.5 (R4.2)
/PD3: J2.5, RA2.6 (R3.2)
/PD4: J2.6, RA2.7 (R2.2)
/PD5: J2.7, RA2.8 (R1.2)
/PD6: J2.8, RA1.5 (R4.2)
/PD7: J2.9, RA1.6 (R3.2)
/USB+: J1.A6 (D+), J1.B6 (D+), U1.15 (USBD+)
/USB-: J1.A7 (D-), J1.B7 (D-), U1.16 (USBD-)
/WR: RA3.4 (R4.1), U1.14 (WR)
/~INIT: J2.16, RA3.8 (R1.2)
/~PWREN: Q1.1 (G), R3.1, U1.12 (~PWREN)
/~RESET: R2.1, RA3.1 (R1.1), SW1.2, U1.19 (~RESET)
/~SELIN: J2.17, Q2.1 (G), R5.1, R8.2
/~STROBE: J2.1, Q2.3 (D)
/~STR: J2.10, Q2.2 (S), R1.1, RA3.5 (R4.2)
/~TXE: RA1.2 (R2.1), U1.22 (~TXE)
GND: C1.1, C2.2, C3.2, C4.2, J1.A1B12 (GND), J1.B1A12 (GND), J1.S (SHIELD), J2.12, J2.18, J2.19, J2.20, J2.21, J2.22, J2.23, J2.24, J2.25, R4.2, R5.2, R6.1, R7.1, SW1.1, U1.7 (GND1), U1.18 (GND2), U1.21 (GND3), U1.25 (AGND), U1.26 (TEST)
unnamed: J1.A5 (CC1), R6.2
unnamed: J1.B5 (CC2), R7.2
unnamed: LED1.2 (A), RA1.8 (R1.2)
unnamed: LED2.1 (K), R8.1
VBUS: C4.1, FB1.1, J1.A4B9 (VBUS), J1.B4A9 (VBUS)
VCC: C2.1, C3.1, FB1.2, Q1.2 (S), R1.2, R2.2, R3.2, U1.4 (VCCIO), U1.13 (~RD), U1.20 (VCC)

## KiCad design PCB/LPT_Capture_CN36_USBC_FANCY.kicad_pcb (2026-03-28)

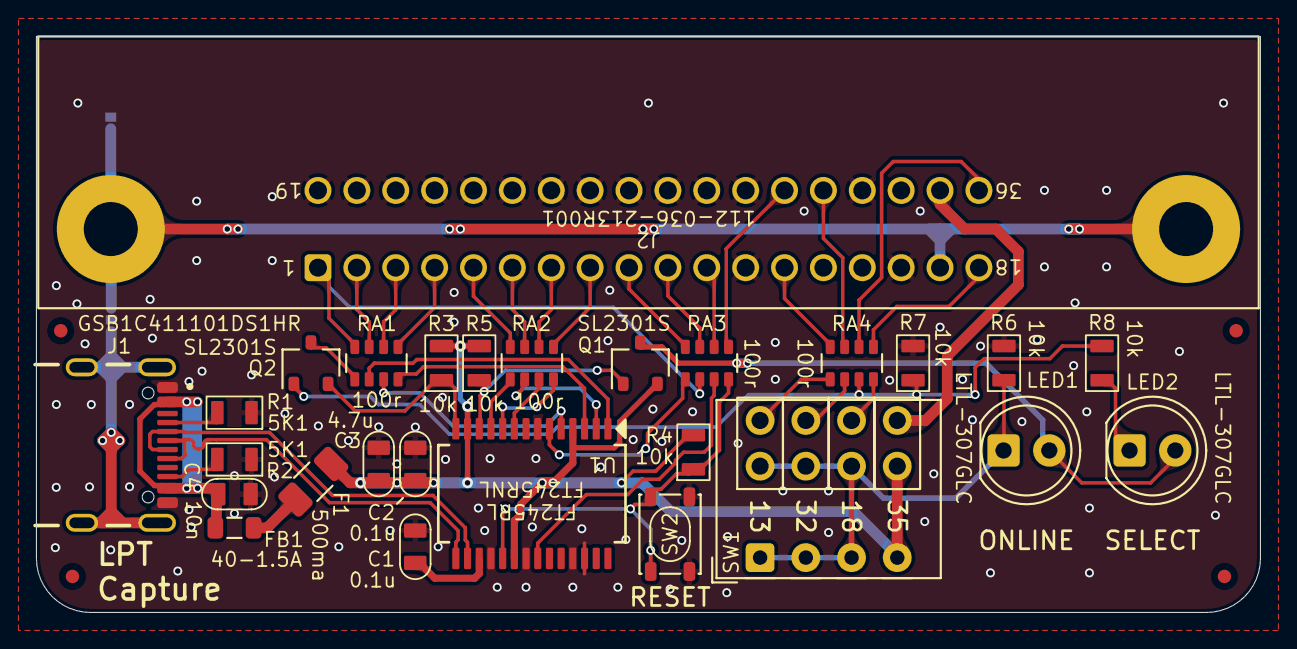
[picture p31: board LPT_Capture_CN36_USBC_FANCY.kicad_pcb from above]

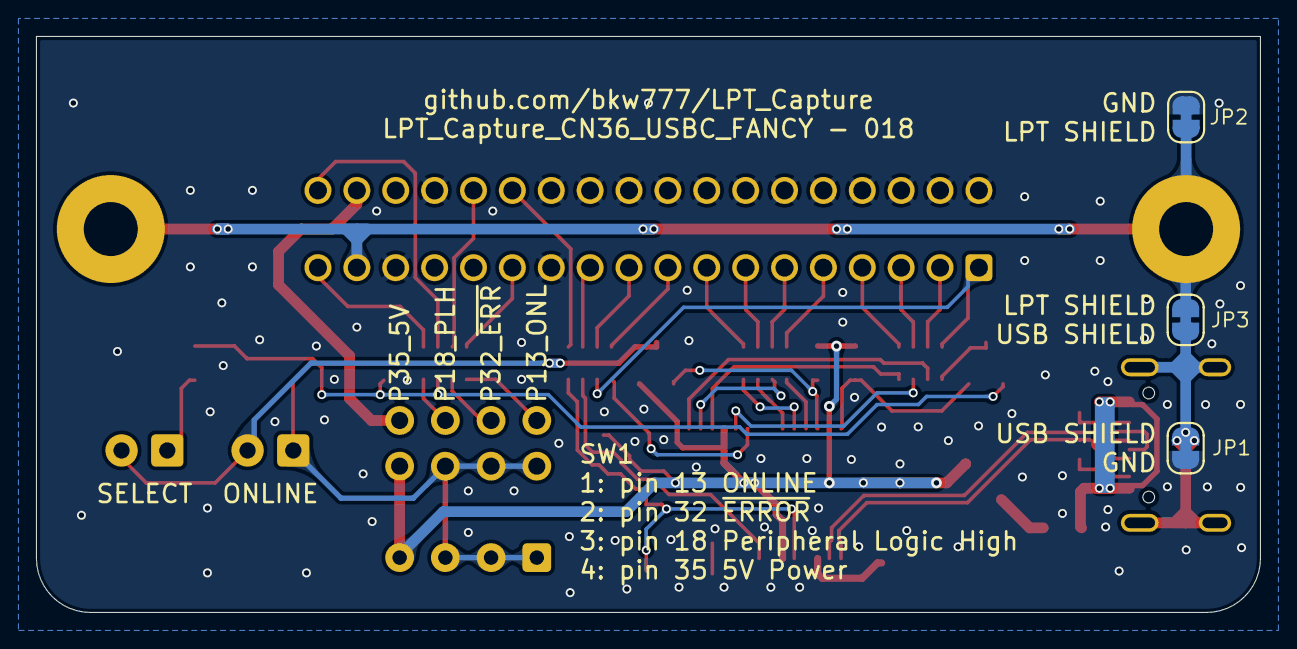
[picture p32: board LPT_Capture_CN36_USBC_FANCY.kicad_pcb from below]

Board: 2 copper layers, 68.0 x 32.0 mm, 31 parts (3 on the bottom side), 48 nets.

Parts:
C1, C2: 0.1u; C_0805
C3: 4.7u; C_0805
C4: 10n; C_0805
F1: 500ma; F_1206
FB1: 40-1.5A; L_0805
J1: GSB1C411101DS1HR; USBC_Receptacle_16pin_top_mount
J2: 112-036-213R001; Centronics_36F_RA_THT
JP1: GND_USBSHLD; SolderJumper-2_P1.3mm_Bridged_RoundedPad1.0x1.5mm
JP2: GND_LPTSHLD; SolderJumper-2_P1.3mm_Bridged_RoundedPad1.0x1.5mm
JP3: USBSHLD_LPTSHLD; SolderJumper-2_P1.3mm_Bridged_RoundedPad1.0x1.5mm
LED1, LED2: LTL-307GLC; LED_D5.0mm
N1: Housing; Housing_CN36
Q1, Q2: SL2301S; SOT-23
R1, R2: 5K1; R_0805
R3, R4, R5, R6, R7, R8: 10k; R_0805
RA1, RA2, RA3, RA4: 100r; R_Array_Convex_4x0603
SW1: SW_DIP_x04; SW_DIP_SPST_Jumper_Dual_x04
SW2: RESET; SW_SPST_PTS810
U1: FT245RL; SSOP-28

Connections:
/3v3: C1.1, U1.17 (3V3OUT)
/5V: J2.35, SW1.5
/BUSY: J2.11, RA3.6 (R3.2)
/D0: RA1.2 (R2.1), U1.1 (D0)
/D1: RA1.3 (R3.1), U1.5 (D1)
/D2: RA1.4 (R4.1), U1.3 (D2)
/D3: RA2.1 (R1.1), U1.11 (D3)
/D4: RA2.2 (R2.1), U1.2 (D4)
/D5: RA2.3 (R3.1), U1.9 (D5)
/D6: RA2.4 (R4.1), U1.10 (D6)
/D7: RA3.1 (R1.1), U1.6 (D7)
/ON: LED1.1 (K), R6.1, SW1.1, SW1.2, SW1.3
/ONLINE: J2.13, RA4.8 (R1.2)
/PD0: J2.2, RA1.7 (R2.2)
/PD1: J2.3, RA1.6 (R3.2)
/PD2: J2.4, RA1.5 (R4.2)
/PD3: J2.5, RA2.8 (R1.2)
/PD4: J2.6, RA2.7 (R2.2)
/PD5: J2.7, RA2.6 (R3.2)
/PD6: J2.8, RA2.5 (R4.2)
/PD7: J2.9, RA3.8 (R1.2)
/PLH: J2.18, RA4.5 (R4.2)
/PWREN: LED1.2 (A), LED2.2 (A), Q1.3 (D)
/USB+: J1.A6 (D+), J1.B6 (D+), U1.15 (USBD+)
/USB-: J1.A7 (D-), J1.B7 (D-), U1.16 (USBD-)
/WR: Q2.2 (S), R3.1, U1.14 (WR)
/sONL: RA4.1 (R1.1), SW1.8
/sPLH: RA4.4 (R4.1), SW1.6
/~ACK: J2.10, RA3.7 (R2.2)
/~ERROR: J2.32, RA4.7 (R2.2)
/~INIT: J2.31, RA3.5 (R4.2)
/~PWREN: Q1.1 (G), R5.1, U1.12 (~PWREN)
/~RESET: R4.1, RA3.4 (R4.1), SW2.2, U1.19 (~RESET)
/~SELIN: J2.36, RA4.6 (R3.2)
/~SEL: Q2.1 (G), R7.1, R8.2, RA4.3 (R3.1)
/~STROBE: J2.1, RA1.8 (R1.2), RA3.2 (R2.1)
/~STR: Q2.3 (D), RA1.1 (R1.1)
/~TXE: RA3.3 (R3.1), U1.22 (~TXE)
/~sERR: RA4.2 (R2.1), SW1.7
GND: C1.2, C2.2, C3.2, C4.2, J1.A1B12 (GND), J1.B1A12 (GND), J2.12, J2.16, J2.19, J2.20, J2.21, J2.22, J2.23, J2.24, J2.25, J2.26, J2.27, J2.28, J2.29, J2.30, J2.33, JP1.1 (A), JP2.1 (A), R1.1, R2.1, R6.2, R7.2, SW2.1, U1.7 (GND1), U1.18 (GND2), U1.21 (GND3), U1.25 (AGND), U1.26 (TEST)
LPT_SHIELD: J2.17, J2.S (Shield), JP2.2 (B), JP3.2 (B)
unnamed: F1.1, FB1.2
unnamed: J1.A5 (CC1), R1.2
unnamed: J1.B5 (CC2), R2.2
unnamed: LED2.1 (K), R8.1
USB_SHIELD: J1.S (SHIELD), JP1.2 (B), JP3.1 (A)
VBUS: C4.1, FB1.1, J1.A4B9 (VBUS), J1.B4A9 (VBUS)
VCC: C2.1, C3.1, F1.2, Q1.2 (S), R3.2, R4.2, R5.2, SW1.4, U1.4 (VCCIO), U1.13 (~RD), U1.20 (VCC)

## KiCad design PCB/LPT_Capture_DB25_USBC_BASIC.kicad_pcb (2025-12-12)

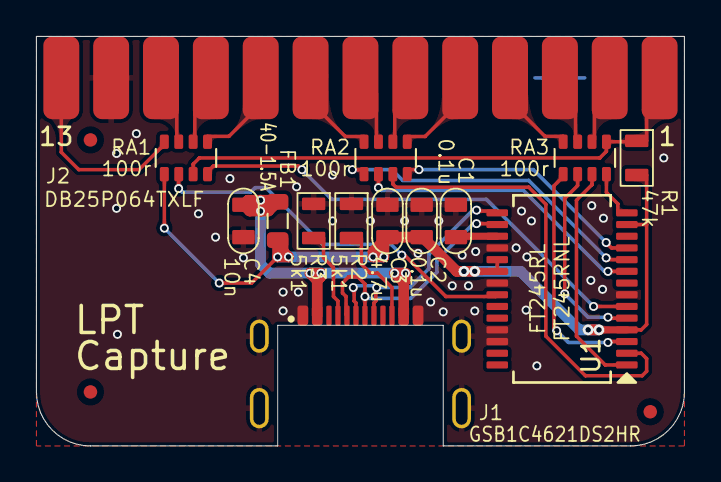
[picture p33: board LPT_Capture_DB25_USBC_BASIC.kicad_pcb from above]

Board: 2 copper layers, 36.0 x 22.8 mm, 15 parts (0 on the bottom side), 31 nets.

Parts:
C1, C2: 0.1u; C_0805
C3: 4.7u; C_0805
C4: 10n; C_0805
FB1: 40-1.5A; L_0805
J1: GSB1C4621DS2HR; USBC_Receptacle_16pin_mid_mount
J2: DB25P064TXLF; DSUB-25_Male_EdgeMount_P2.77mm
N1: 956-025-010R031; DSUB-25_Housing
R1: 47k; R_0805
R2, R3: 5k1; R_0805
RA1, RA2, RA3: 100r; R_Array_Convex_4x0603
U1: FT245RL; SSOP-28

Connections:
/3v3: C1.1, U1.17 (3V3OUT)
/BUSY: J2.11, RA1.7 (R2.2)
/D0: RA3.3 (R3.1), U1.1 (D0)
/D1: RA3.2 (R2.1), U1.5 (D1)
/D2: RA3.1 (R1.1), U1.3 (D2)
/D3: RA2.4 (R4.1), U1.11 (D3)
/D4: RA2.3 (R3.1), U1.2 (D4)
/D5: RA2.2 (R2.1), U1.9 (D5)
/D6: RA2.1 (R1.1), U1.10 (D6)
/D7: RA1.4 (R4.1), U1.6 (D7)
/ONLINE: J2.13, RA1.8 (R1.2)
/PD0: J2.2, RA3.6 (R3.2)
/PD1: J2.3, RA3.7 (R2.2)
/PD2: J2.4, RA3.8 (R1.2)
/PD3: J2.5, RA2.5 (R4.2)
/PD4: J2.6, RA2.6 (R3.2)
/PD5: J2.7, RA2.7 (R2.2)
/PD6: J2.8, RA2.8 (R1.2)
/PD7: J2.9, RA1.5 (R4.2)
/USB+: J1.A6 (D+), J1.B6 (D+), U1.15 (USBD+)
/USB-: J1.A7 (D-), J1.B7 (D-), U1.16 (USBD-)
/WR: RA3.4 (R4.1), U1.14 (WR)
/~ACK: J2.10, RA1.6 (R3.2)
/~RESET: J2.15, J2.16
/~STROBE: J2.1, R1.1, RA1.3 (R3.1), RA3.5 (R4.2)
/~TXE: RA1.2 (R2.1), U1.22 (~TXE)
GND: C1.2, C2.2, C3.2, C4.2, J1.A1B12 (GND), J1.B1A12 (GND), J1.S (SHIELD), J2.12, J2.18, J2.19, J2.20, J2.21, J2.22, J2.23, J2.24, J2.25, R2.1, R3.1, U1.7 (GND1), U1.18 (GND2), U1.21 (GND3), U1.25 (AGND), U1.26 (TEST)
unnamed: J1.A5 (CC1), R3.2
unnamed: J1.B5 (CC2), R2.2
VBUS: C4.1, FB1.1, J1.A4B9 (VBUS), J1.B4A9 (VBUS)
VCC: C2.1, C3.1, FB1.2, R1.2, RA1.1 (R1.1), U1.4 (VCCIO), U1.13 (~RD), U1.19 (~RESET), U1.20 (VCC)

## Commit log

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2021-06-06 layout fine tuning
    [LPT_Capture.kicad_pcb, LPT_Capture.sch]
2021-06-07 tie select high
    [LPT_Capture.kicad_pcb, LPT_Capture.sch]
2021-06-08 small layout tweaks
    [LPT_Capture.kicad_pcb]
2021-06-09 inverted centered usb jack
    [956-025-0Y0R0Y1.STEP, LPT_Capture.BOM.csv, LPT_Capture.kicad_pcb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]
2021-06-10 db25 solder cups
    [LPT_Capture.BOM.csv, LPT_Capture.kicad_pcb]
2021-06-16 v004 rn footprints, add fb1 c3 c4
    [LPT_Capture.kicad_pcb, LPT_Capture.sch]
2021-06-16 bom & readme
    [LPT_Capture.BOM.csv, LPT_Capture.kicad_pcb, LPT_Capture.sch]
2021-06-16 more available fb1 in bom
    [LPT_Capture.BOM.csv]
2021-06-22 minor layout nudges
    [LPT_Capture.kicad_pcb]
2021-06-28 better usb port attachment
    [LPT_Capture.kicad_pcb]
2021-06-29 v008, better usb port
    [LPT_Capture.BOM.csv, LPT_Capture.kicad_pcb, LPT_Capture.sch]
2021-06-29 version silkscreen
    [LPT_Capture.kicad_pcb]
2021-06-30 disconnect Select
    [LPT_Capture.BOM.csv, LPT_Capture.kicad_pcb, LPT_Capture.sch]
2023-01-28 kicad 6, minor layout tweaks, ft245rl symbol
    [LPT_Capture.kicad_pcb, LPT_Capture.kicad_sch, LPT_Capture.sch]
2023-09-11 minor routing and silkscreen touch ups
    [LPT_Capture.kicad_pcb, LPT_Capture.kicad_sch]
2023-09-12 minor routing straighten
    [LPT_Capture.kicad_pcb]
2024-06-25 caps units, sch clutter
    [LPT_Capture.kicad_pcb, LPT_Capture.kicad_sch]
2024-08-31 add MPN to symbols, export fab_bom & centroid
    [LPT_Capture.BOM.csv, LPT_Capture.fab_bom.csv, LPT_Capture.kicad_pcb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]
2025-11-19 double vias on power
    [LPT_Capture.kicad_pcb, LPT_Capture.kicad_sch]
2025-12-01 update eol FT245R to FT245RN
    [LPT_Capture.BOM.csv, LPT_Capture.bom.csv, LPT_Capture.kicad_pcb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]
2025-12-01 component library & models
    [LPT_Capture.kicad_pcb, LPT_Capture.kicad_sch]
2025-12-01 update bom
    [LPT_Capture.bom.csv]
2025-12-05 cleanup symb & footp libs, add ONLINE
    [LPT_Capture.bom.csv, LPT_Capture.kicad_pcb]
2025-12-10 sch notes compatible db25 parts
    [LPT_Capture.kicad_sch]
2025-12-10 strobe>ack via unused 100r
    [LPT_Capture.kicad_pcb, LPT_Capture.kicad_sch]
2025-12-12 pull db25_usbc_basic into main
    [LPT_Capture_DB25_USBC_BASIC.bom.csv, LPT_Capture_DB25_USBC_BASIC.kicad_pcb, LPT_Capture_DB25_USBC_BASIC.kicad_sch]
2025-12-12 pull db25_microusb_fancy into main
    [LPT_Capture_DB25_MicroUSB_BASIC.bom.csv, LPT_Capture_DB25_MicroUSB_BASIC.kicad_pcb, LPT_Capture_DB25_MicroUSB_BASIC.kicad_sch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]
2025-12-12 fix db25_microusb_fancy filenames, pull db25_usbc_fancy into main
    [LPT_Capture.bom.csv, LPT_Capture_DB25_MicroUSB_FANCY.bom.csv, LPT_Capture_DB25_MicroUSB_FANCY.kicad_pcb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]
2025-12-12 pull c36_usbc_fancy into main
    [LPT_Capture_C36_USBC.bom.csv, LPT_Capture_Centronics_USBC_FANCY.kicad_pcb, LPT_Capture_Centronics_USBC_FANCY.kicad_sch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]
2025-12-12 centronics control flow arrows
    [LPT_Capture_Centronics_USBC_FANCY.kicad_sch]
2025-12-13 diff pair len match
    [LPT_Capture_Centronics_USBC_FANCY.kicad_pcb, LPT_Capture_DB25_USBC_FANCY.kicad_pcb, LPT_Capture_DB25_USBC_FANCY.kicad_sch]
2025-12-14 basic cover for CN36
    [LPT_Capture_CN36_USBC.scad]
2025-12-14 begin fancy cn36 cover
    [LPT_Capture_CN36_USBC.scad]
2025-12-14 cn36 tiny repositions
    [LPT_Capture_CN36_USBC_FANCY.kicad_pcb]
2025-12-15 cn36 cover
    [LPT_Capture_CN36_USBC.scad]
2025-12-16 varied cn36 models
    [LPT_Capture_CN36_USBC.scad, LPT_Capture_CN36_USBC_FANCY.kicad_pcb, LPT_Capture_CN36_USBC_FANCY.kicad_sch]
2025-12-18 cn36 screwless snap-on full shell cover
    [LPT_Capture_CN36_USBC.scad]
2025-12-19 cn36: board dims, leds, housing
    [LPT_Capture_CN36_USBC.scad, LPT_Capture_CN36_USBC_FANCY.bom.csv, LPT_Capture_CN36_USBC_FANCY.kicad_pcb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]
2025-12-20 cn36 cover shape
    [LPT_Capture_CN36_USBC.scad, LPT_Capture_CN36_USBC_FANCY.kicad_pcb]
2025-12-20 cn36: missing datasheet, add RA4, refactor parts of cover scad
    [LPT_Capture_CN36_USBC.scad, LPT_Capture_CN36_USBC_FANCY.bom.csv, LPT_Capture_CN36_USBC_FANCY.kicad_pcb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]
2025-12-22 cn36 add F1 SW1
    [LPT_Capture_CN36_USBC.scad, LPT_Capture_CN36_USBC_FANCY.bom.csv, LPT_Capture_CN36_USBC_FANCY.kicad_pcb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]
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2025-12-24 cn36 add jp1,2,3
    [LPT_Capture_CN36_USBC_FANCY.bom.csv, LPT_Capture_CN36_USBC_FANCY.kicad_pcb, LPT_Capture_CN36_USBC_FANCY.kicad_sch]
2025-12-24 cn36 add R8 current limit led when /SELIN driven low
    [LPT_Capture_CN36_USBC_FANCY.bom.csv, LPT_Capture_CN36_USBC_FANCY.kicad_pcb, LPT_Capture_CN36_USBC_FANCY.kicad_sch]
2025-12-25 db25-usbc-fancy add R8 current limit led when /SELIN driven low
    [LPT_Capture_DB25_USBC_FANCY.bom.csv, LPT_Capture_DB25_USBC_FANCY.kicad_pcb, LPT_Capture_DB25_USBC_FANCY.kicad_sch]
2025-12-25 db25-microusb-fancy add R6 current limit led when /SELIN driven low
    [LPT_Capture_DB25_MicroUSB_FANCY.bom.csv, LPT_Capture_DB25_MicroUSB_FANCY.kicad_pcb, LPT_Capture_DB25_MicroUSB_FANCY.kicad_sch]
2025-12-26 cn36 dip sw and housing
    [LPT_Capture_CN36_USBC.scad, LPT_Capture_CN36_USBC_FANCY.bom.csv, LPT_Capture_CN36_USBC_FANCY.kicad_pcb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]
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2026-03-26 cover scad include vs use
    [LPT_Capture_CN36_USBC.scad]
2026-03-26 fancy versions - prevent backfeed through online led
    [LPT_Capture_CN36_USBC_FANCY.kicad_pcb, LPT_Capture_CN36_USBC_FANCY.kicad_sch, LPT_Capture_DB25_MicroUSB_FANCY.kicad_pcb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]
2026-03-26 cn36 ground paths around sw1
    [LPT_Capture_CN36_USBC_FANCY.kicad_pcb]
2026-03-28 cn36 add reset button
    [LPT_Capture_CN36_USBC.scad, LPT_Capture_CN36_USBC_FANCY.bom.csv, LPT_Capture_CN36_USBC_FANCY.kicad_pcb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]
2026-04-18 DB25_USBC_FANCY add reset button
    [LPT_Capture_DB25_USBC_FANCY.bom.csv, LPT_Capture_DB25_USBC_FANCY.kicad_pcb, LPT_Capture_DB25_USBC_FANCY.kicad_sch]

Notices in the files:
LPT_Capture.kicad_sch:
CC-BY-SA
